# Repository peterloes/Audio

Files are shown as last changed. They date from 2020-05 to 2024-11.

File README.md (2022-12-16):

# Audio
 designed with MOMO 
 
Authors: Loës P., Kempenaers B.(2020) 

Firmware not reviewed. 

Platform for animal observation and manipulation.

Supported:
- FN-RM01 MP3/WAV Audio Recorder and Player Module (Website: www.flyrontech.com)

The Project is used to playback and record sounds, target manipulated via pit-tag numbers.
Uses the Audio Module FN-RM01 which handles automatic playback and record files.

An efficient application to monitor and control animal behaviour in wildlife
as well as in laboratory settings

-	Targeted manipulation of 1000 and more individuals
- Pit-tag numbers targeting Playback-Soundfiles or Record-Soundfiles 
- Playback Audio files P001.wav/mp3 up to P005.wav/mp3 over time
- Random Playback Audio files P001.wav/mp3 up to P005.wav/mp3 over time
- Record Audio files R001.wav up to R999.wav over time
- Combined Audio Playback and Record over time
- There are two special IDs:

  "ANY" means there was a transponder detected, but its ID is not listed.

  "UNKNOWN" means that NO transponder could be detected

My image

-	Low power consumption and specific data collection lead to long lasting collection periods
-	Applicable world-wide due to its compatibility with different types of radio clock receivers 
-	Data-transfer to external devices, such as personal computers
- Time Synchronization with atomic clock once a day to ensure optimal data quality
- Application Current Control twice a day
- Forecast for Battery-Change implemented
- Energy Bypass so that Date and Time are maintained even when changing battery
- Hyperterminal Output to get real-time data to the computer/laptop

My image

Prototype: Smart Nest Box with microphone and speaker on top

https://github.com/peterloes/Audio/blob/master/Getting_Started_Tutorial/1_poster_overview.pdf

Raw data on SD Card:

https://github.com/peterloes/Audio/blob/master/Getting_Started_Tutorial/6_raw_data.txt

Configuration data on SD Card:

https://github.com/peterloes/Audio/blob/master/Software/CONFIG.TXT

Mainboard:

https://github.com/peterloes/MOMO

Optional components:

https://github.com/peterloes/Booter_RFID-MS_MOMO_TAMDL

https://github.com/peterloes/Clock_receiver_RFID-MS_MOMO_TAMDL

Manufacture:

https://github.com/peterloes/Audio/blob/master/Getting_Started_Tutorial/5_Supplier.txt

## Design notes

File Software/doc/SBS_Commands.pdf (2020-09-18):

# Projekt U-BMS2-4

# SBS-

# Commands

# SBS Commands

Device Address | | | | | | 0x0A
ManufacturerAccess | | | | | | 0x00

Read word

RemainingCapacityAlarm | 0x01

Read word
Rückgabe des remainingCapacityAlarm-Wertes in [mAh].

Wenn die Restkapazität(remainingCapacity) kleiner als der Wert vom RemainingCapacityAlarm ist, sendet die Batterie eine Alarmwarnung zum Host. Der RemainingCapacityAlarm-Flag im Battery-Status wird gesetzt.

RemainingTimeAlarm | 0x02

Read word
Rückgabe des remainingTimeAlarm -Wertes in [min].

Wenn die durchschnittliche Entladezeit des Akkus(AverageTimeToEmpty) kleiner als der Wert vom
RemainingTimeAlarm | ist, | sendet | die | Batterie | eine | Alarmwarnung | zum | Host. | Der
RemainingTimeAlarm-Flag im Battery-Status wird gesetzt.
Battery Mode | | | | | | 0x03

Read word

Bit | Beschreibung

### 12 BALANCING CELL3

### 11 BALANCING CELL2

### 10 BALANCING CELL1

### 6 BALANCING CELL4

### 5 Deep Under Voltage recovery(DUVRD) Bit vom FET Control and Status-Register

(FCSR)

### 4 Current Protection Status (CPS) Bit vom FET Control and Status-Register (FCSR)

### 3 Discharge FET (DFE) Bit vom FET Control and Status-Register (FCSR)

### 2 Charge FET (CFE) Bit vom FET Control and Status-Register (FCSR)

CoreTemperature | 0x08

Read word
Die aktuelle Chip-Temperatur in [°K]
Voltage | 0x09

Read word
Die gesamte Akkuspannung in [mV]
BatteryCurrent | 0x0A

Read word
Der aktuelle Strom in [mA], der aus bzw. in den Akkupack durchfließt.
BatteryAverageCurrent | 0x0B

Read word
Der durchschnittliche Strom des Akkupacks in [mA]
RelativeStateOfCharge | 0x0D

Read word
Der relative Ladezustand des Akkupacks in [%]
AbsoluteStateOfCharge | 0x0E

Read word
Der absolute Ladezustand des Akkupacks in [%]
RemainingCapacity | 0x0F

Read word
Die Restkapazität des Akkupacks in [mAh]
FullChargeCapacity | 0x10

Read word
Rückgabe der vollen Ladekapazität in [mAh]
RunTimeToEmpty | 0x11

Read word
Die Ladezeit in [min]
AverageTimeToEmpty | 0x12

Read word
Die durchschnittliche Entladezeit [min]
AverageTimeToFull | 0x13

Read word
Die durchschnittliche Ladezeit in [min]

ChargingCurrent | 0x14

Read word
Der Ladestrom in [mA]
ChargingVoltage | 0x15

Read word
Die maximale Ladespannung in [mV]
Battery Status (flags) | 0x16

Read word

Bit | Beschreibung

### 15 Over Charged Alarm

Überprüfung des chargingProhibited-Flags

### 14 Terminate Charge Alarm

Überprüfung des voltageTooHigh-Flags

### 12 Over Temp Alarm

Überprüfung des cellTemperatureTooHigh -Flags

### 11 Terminante Discharge Alarm

Dieses Bit wird gesetzt, wenn die Restkapazität unter dem definierten Wert von SBS_TERMINATE_DISCHARGE_LIMIT (Standard 5mAh) liegt. Wenn ein Ladegerät erkannt wird, wird dieses Bit gelöscht.

### 10 Battery Protection Triggered

Dieses Bit wird gesetzt, wenn die Batterieschutz-Hardware die FETs ausschaltet.

### 9 Remaining Capacity Alarm

Dieses Bit wird gesetzt, wenn die Restkapazität weniger als der definierte Wert des Restkapazität-Alarms(RemainingCapacityAlarm) ist.

### 8 Remaining Time Alarm :

Wenn die durchschnittlische Entladezeit (AverageTimeToEmpty) kleiner als der definierte Wert des Entladezeit-Alarms (RemainingTimeAlarm) ist, wird dieses Bit gesetzt.

### 7 Initialized

Dieses Bit wird gesetzt, wenn die Initialisierung erfolgreich abgeschlossen ist.

### 6 Discharging

Dieses Bit wird gesetzt, wenn ein Entladestrom fließt.

### 5 Fully Charged

Dieses Bit wird gesetzt, wenn die Batterie vollständig geladen ist. Wenn ein Entladestrom aus der Batterie fließt, der höher als der Standby-Stromwert ist, wird dieses Bit gelöscht.

### 4 Fully Discharged

Dieses Bit wird gesetzt, wenn die Restkapazität der Batterie bzw. die Zellenspannung sehr niedrig ist. Wenn der relative Ladezustand über 20% steigt, wird dieses Bit gelöscht.

ChargerCycleCount | 0x17

Read word
Die Anzahl der Ladezyklen
DesignCapacity | 0x18

Read word
Die Nennkapazität in [mAh]
DesignVoltage | 0x19

Read word
Die Nennspannung in [mV]
SpecificationInfo | 0x1A

Read word
Die Spezifikation-Info (Version und Revision-Nummer)
ManufactureDate | 0x1B

Read word
Das Herstellungsdatum
SerialNumber | 0x1C

Read word
Die Seriennummer
ManufacturerName | 0x20

Read Block
Der Name des Herstellers
DeviceName | 0x21

Read Block
Der Name des Gerätes
DeviceChemistry | 0x22

Read Block
Die chemische Bezeichnung des Gerätes
ManufacturerData | 0x23

Read Block
Die Herstellerdaten
ShuntResistance | 0x2A

Read word
Der Wert des Shunt-Widerstands in [µOhm]

CellsInSeries | 0x3C

Read word
Anzahl der verwendeten Zellen in Serie
OverCurrentReactionTime | 0x3D

Read word
Überstrom Reaktionszeit Stufe 1
OverCurrentCharge | 0x3E

Read word
Überladestrom Stufe 1
OverCurrentDischarge | 0x3F

Read word
Überentladestrom Stufe 1
HighCurrentReactionTime | 0x40

Read word
Überstrom Reaktionszeit Stufe 2
HighCurrentCharge | 0x41

Read word
Überladestrom Reaktionszeit Stufe 2
HighCurrentDischarge | 0x42

Read word
Überentladestrom Stufe 2
VoltageCell4 | 0x44

Read word
Rückgabe der Spannung der Zelle 4 in [mV]
VoltageCell3 | 0x45

Read word
Rückgabe der Spannung der Zelle 3 in [mV]
VoltageCell2 | 0x46

Read word
Rückgabe der Spannung der Zelle 3 in [mV]

VoltageCell1 | 0x47

Read word
Rückgabe der Spannung der Zelle 1 in [mV]
CellMinVoltage | 0x54

Read word
Die minimale Zellenspannung in [mV]
CellMaxVoltage | 0x55

Read word
Der Wert der maximalen Zellenspannung in [mV]
CellPowerOffVoltage | 0x55

Read word
Der Wert der Zellenspannung in [mV], bei der das BMS in den PowerOffModus geht

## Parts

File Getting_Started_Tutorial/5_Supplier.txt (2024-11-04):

Active antennas
DCF77 Empfänger AASV DCFn PON/Ri/1m Aktivantenne SV DCFn 

HKW-Elektronik GmbH
Jörg Schneider

Eisenacher Str. 42 b
99848 Wutha-Farnroda / Thür.
Germany
Phone:  +49 (0)36921 3080 130
mailto:    schneider@hkw-elektronik.de
www.hkw-elektronik.de

Lightbarriers for front plate nestbox 
Doppel - Lichtschranke Art.Nr. P00700 (Lichtschranken in Frontplatten):

SWISSSENSOR AG
Geschäftsleitung Hermann Beer

Steinacherstrasse 4
CH-9327 Tübach
Germany
Tel. +41(0)71 845 24 24
mailto:beer@swisssensor.ch
www.swisssensor.ch

Lithium Ionen rechargeable battery pack Art.Nr. 60.16294 Panasonic NCR 18650GA 4S2P
14,4Volt 6900mAh inklusive SMBus Kabel je. 150mm 

DYNAMIS Batterien GmbH
Josef Pfeil

Brühlstraße 15  D- 78465 Dettingen / Konstanz
Tel. +49 (0) 75 33/93 669-15
mailto:josef.pfeil@dynamis-batterien.de
www.dynamis-batterien.de

FN-RM01 MP3/WAV Audio Recorder and Player Module
Flyron Technology Co., Ltd.
Kevin Xu

Skype ID: kevinxu8410
Phone: +86-186 6501 8673
E-mail: kevin.xu@flyrontech.com
Website: www.flyrontech.com

Supplier of all Electronic Boards

Top-Print Electronic GmbH
Oskar Schmid

Rosenheimer Landstr. 129a
85521 Ottobrunn
Germany
Tel.: +49-89-60668047
Fax: +49-89-60668049
mailto: info@top-print.eu
https://www.leiterplatten-muenchen.de/

RFID reader
Nanomodule Multi 125LV A/1.11 (T3NM-LV) 125kHz +/-0,5% Art.Nr. ART10413
ANT002 Rundspule 47mm, 490µH Art.Nr. ART 10668

Elatec GmbH
Felix Ellspermann

Zeppelinstr. 1
82178 Puchheim 
Germany
Tel: +49 89 552 9961 120
mailto: f.ellspermann@elatec.com
www.elatec-rfid.com

Small sized transponder, not uniqued.
GlassTag 1,41x8,3mm EM4305 134kHz

Rasmus Forntheil
Product Manager Animal ID
RBIS Europe, Smartrac Specialty GmbH

e: rasmus.forntheil@eu.averydennison.com
t: +49 (0) 2265 9919-14  |  m: +49 (0) 173 5688184
Gewerbeparkstr. 10, 51580 Reichshof-Wehnrath, Germany

Internet: https://www.averydennison.com/en/home.html

Protective coating with Schmelzharz Bectron MR3404

KC – Kunststoff- Chemische Produkte GmbH
Holger Sarau-Burghardt

Leonberger Straße 86 
DE 71292 Friolzheim
phone: +49 (0)7044 9425 13
e-mail: h.sarau-burghardt@kc-produkte.com
http: www.conformalcoating.de

Industrial SD Cards ATP 2GB
https://www.atpinc.com/products/industrial-sd-cards

FTDI Chip cable (3.5mm Audio Jack to USB)
TTL-232R-3V3-AJ

Housing
https://www.spelsberg.de/industrieleergehaeuse/glatt-mit-befestigungsnocken/20100701/
TG PC 1612-9-to
Artikelnummer: 20100701 | Maße: 162 x 122 x 90 mm
Leergehäuse IP66 / IP67 Polycarbonat

Docklight RS232 Terminal / RS232 Monitor
https://docklight.de/information/

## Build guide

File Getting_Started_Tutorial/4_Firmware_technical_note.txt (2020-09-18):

MOMO (Multifunctional Mainboard to Observe and Manipulate Organisms) 
is an application to automate the recording and manipulation of animal behavior.

Version 1.3
- Added support for battery controller TI bq40z50.
  LogBatteryInfo: Removed SBS_ManufacturerData.
  Display SBS_RunTimeToEmpty in days/hours/min.
  Display SBS_SerialNumber as hex value.
- CheckAlarmTime to call the respective alarm action if the current time match the alarm time.
  There is only one alarm time. ON_TIME_1/ OFF_TIME_1 --> Alarm 1 (08:30 - 16:00) is ON. 
  Reading the configuration file CONFIG.TXT from the SD-Card and set-up alarm action.
- Corrected decoding of Short-Range(SR) RFID Reader transponder ID.
- Implemented new feature "Absence Detection" which reports when a transponder is no more detected.
- When the "Absence Detection" is configured, disabling the RFID reader is deferred as long as a transponder is still present.

This application consists of the following modules:
 - main.c - Initialization code and main execution loop.
 - DMA_ControlBlock.c - Control structures for the DMA channels.
 - Control.c - Sequence Control module.
 - CfgData.c - Handling of configuration data.
 - ExtInt.c - External interrupt handler.
 - AlarmClock.c - Alarm clock and timers facility.
 - DCF77.c - DCF77 Atomic Clock Decoder
 - clock.c - An implementation of the POSIX time() function.
 - LightBarrier.c - Interrupt logic for the two light barriers,
   enables the RFID reader.
 - RFID.c - RFID reader to receive transponder IDs.
 - BatteryMon.c - Battery monitor, periodically reads the state of the
   battery via the SMBus.
 - LEUART.c - The Low-Energy UART can be used as monitoring and debugging
   connection to a host computer.
 - microsd.c - Together with the files "diskio.c" and "ff.c", this module
   provides an implementation of a FAT file system on the @ref ss8.
 - Logging.c - Logging facility to send messages to the LEUART and store
   them into a file on the SD-Card.
 - PowerFail.c - Handler to switch off all loads in case of Power Fail.

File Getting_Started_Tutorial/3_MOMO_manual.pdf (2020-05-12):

## Max Planck Institute for Ornithology

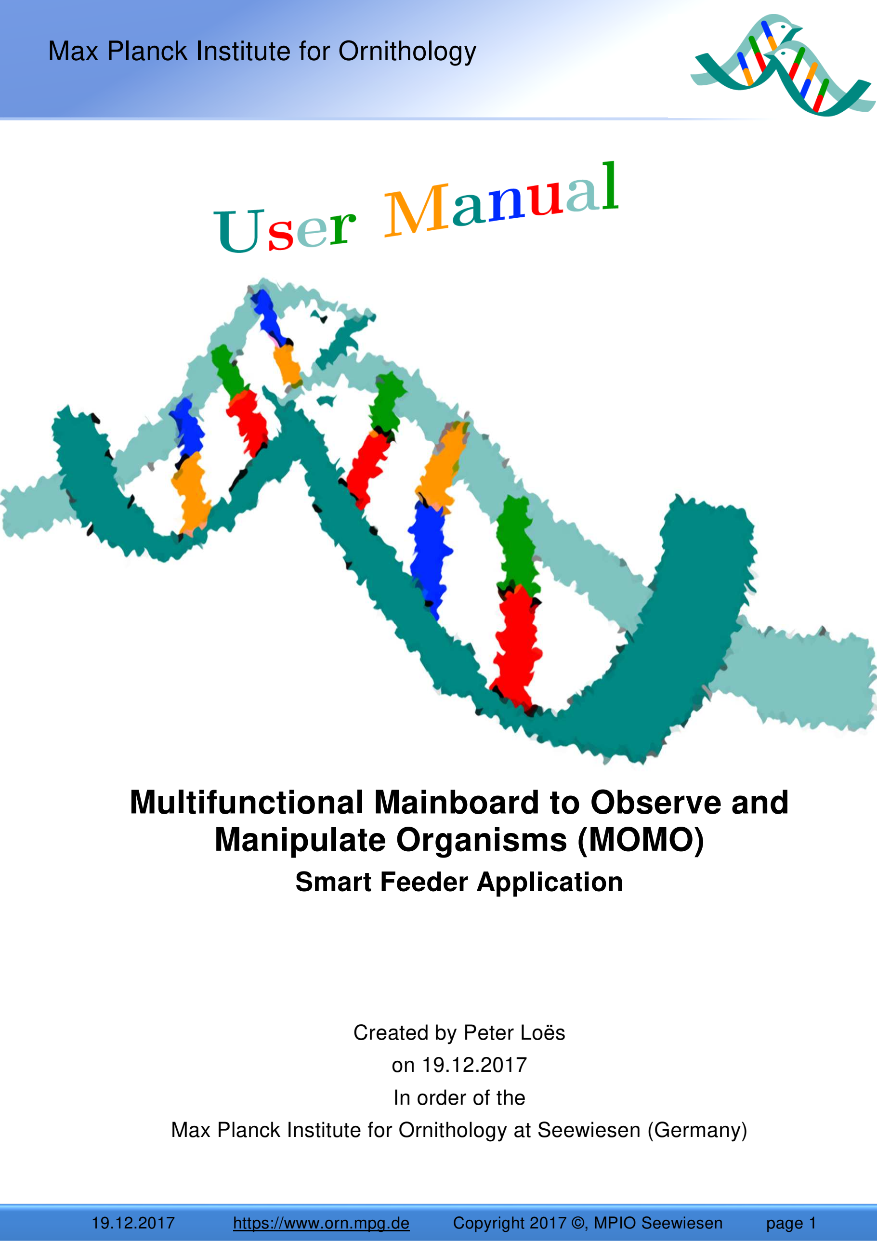
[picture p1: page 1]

19.12.2017 | https://www.orn.mpg.de | Copyright 2017 ©, MPIO Seewiesen | page 1

# Multifunctional Mainboard to Observe and Manipulate Organisms (MOMO)

## Smart Feeder Application

Created by Peter Loës
on 19.12.2017
In order of the
Max Planck Institute for Ornithology at Seewiesen (Germany)

Disclaimer and Copyright

19.12.2017 | https://www.orn.mpg.de | Copyright 2017 ©, MPIO Seewiesen | page 2

## Disclaimer

The Multifunctional Mainboard to Observe and Manipulate Organisms is to be used only as that described in this document. Any other method of usage is not permitted. If damage occurs due to incorrect usage, the manufacturer of the Multifunctional Mainboard to Observe and Manipulate Organisms is not liable.

## Copyright ©

The Copyright for this user manual remains with the manufacturer. Text and figures meet the latest technical status at the time of publication. Subject to change. The content of the user manual shall not affect any claims of the purchaser. The editor also welcomes suggestions of any possible improvements you may have or whether any errors are encountered.

List of abbrevations

19.12.2017 | https://www.orn.mpg.de | Copyright 2017 ©, MPIO Seewiesen | page 3

## List of abbreviations

SF | Smart Feeder
LB | Light Barrier
RFID | radio-frequency identification
EFM | Energy Friendly Microcontroller
PCB | printed circuit board
DCF | D for Deutschland (Germany), C for long-wave transmitter, F due to the vicinity to the Town Frankfurt
ARM | Advanced RISC Machines
SD-CARD | Secure Digital Memory Card
PIT | Passive Integrated Transponder
LEUART | Low Energy Universal Asynchronous Receiver/Transmitter
USB | Universal Serial Bus
MOMO | Multifunctional Mainboard to Observe and Manipulate Organisms

System Overview

19.12.2017 | https://www.orn.mpg.de | Copyright 2017 ©, MPIO Seewiesen | page 4

## System Overview

## General Description of Functions

The Multifunctional Mainboard to Observe and Manipulate Organisms has been developed to record and manipulate animal behaviour. For this purpose, animals got equipped with transponders that can be activated and identified via reading devices. Every animal equipped with a transponder can thereby be identified individually. This technology can be used for every animal species on or in which it is possible to attach a RFID transponder of the size of a rice grain.

Within a population of several individuals carrying a RFID transponder, the Multifunctional Mainboard to Observe and Manipulate Organisms can save the presence and identity of the animals. Whenever an individual with transponder visits a feeder equipped with sensors, the sensor data, transponder code and the timestamp are saved on a SD-card.

Video recordings and visual observations have long been used by biologists to document behaviour of animals and to answer questions about territory, distribution and reproductive behaviour. However, these methods are time consuming, often inexact, and cannot be used when visibility is low (e.g. at night).

To achieve a flexible operation in the field, the Multifunctional Mainboard to Observe and Manipulate Organisms is supplied with electrical energy by a rechargeable accumulator.

The use of electronic devices in the field and nature requires special features in order to operate correctly. Special developments are needed in order to cope with changes in ambient temperature, humidity, pressure and when the electrical power grid is unavailable. However, such developments can be time-consuming and cost-intensive.

Many iterations in the development are needed in order to ensure a stable functioning of electronic products in the wild.

System Overview

19.12.2017 | https://www.orn.mpg.de | Copyright 2017 ©, MPIO Seewiesen | page 5

The Multifunctional Mainboard to Observe and Manipulate Organisms should be placed where the animals of interest often visit, such as feeders, nests, roosts, enclosures or bottlenecks.

One main usage for which the Multifunctional Mainboard to Observe and Manipulate Organisms was developed, is the feeder. Bird behaviour can be manipulated by rationing or even blocking their access to food. The so called ‘Smart Feeder’ records the bird’s presence and therefore provides information about their distribution and foraging behaviour.

A key strength of the Multifunctional Mainboard to Observe and Manipulate Organisms is that it runs autonomously. During the development, special attention was paid developing an energy saving operation, so that a battery pack would only have to be changed every two weeks up to several months, depending on the activity of the smart feeder. The SD cards used have enough memory space to save data for several months of data collection. These low operating expenses make the Multifunctional Mainboard to Observe and Manipulate Organisms (MOMO) ideal for a use in isolated locations without grid connection. Furthermore, biological data is optimally collected when disturbance to the animal’s behaviour due to human presence is minimised. Compared with video recordings and observations, data generation is less error-prone and an increase of data volume is easily realizable. Nevertheless, MOMO also supports an activation and deactivation of video devices or cameras.

MOMO regularly surveys and documents the state of the smart feeder electronic system. A regular evaluation of these data can detect faulty systems and a necessary maintenance can be performed.

The Multifunctional Mainboard to Observe and Manipulate Organisms is currently used for animals with a diameter of less than 70mm, which is contingent upon the antenna of an animal transponder reader. Larger antennas with only marginal overhead are imaginable though, enabling a detection of larger animals as well.

System Overview

19.12.2017 | https://www.orn.mpg.de | Copyright 2017 ©, MPIO Seewiesen | page 6

Some examples of potential uses are:

- nest boxes of birds
- roosting boxes of bats
- studying and monitoring mammals like rats, mice, hamsters, badgers,

squirrels
- reptile research
- studying and monitoring fish
- studying breeding behaviour
- studying movement and dispersal of animals
- choice of nest boxes or roosts

System Overview

19.12.2017 | https://www.orn.mpg.de | Copyright 2017 ©, MPIO Seewiesen | page 7

## System configuration main circuit board

The smart feeder was developed over several years. After five years of development a reliable and efficient version was completed, which is described comprehensively in this manual. Additional detailed information, particularly concerning the electronic configuration, can be found in the datasheet.

Hardware Illustration (MOMO)

System Overview

19.12.2017 | https://www.orn.mpg.de | Copyright 2017 ©, MPIO Seewiesen | page 8
1 | Reset push button | 14 | Gold Cap Capacitor
2 Connections for linear actuator | control | 15 Connecting terminal for the radio clock
3 Connections for two passive | infrared detectors [3.5V@200mA] | 16 Output voltage | 3.5V-11V@ 2.5A for e.g. cameras
4 | Connections for limit switch | 17 | Output voltage 3.5V-11V@ 2.5A for e.g. cameras
5 Power supply for servomotor | [12V@1.5A] | 18 Power supply light barrier
6 Power supply for linear actuator | [12V@1.5A] | 19 Connecting terminal for switchable | RFID readers[12V@0.22A]
7 Connections for switchable power | supplies for three RFID readers | 20 | Connections for the SMBus „System Management Bus“ of the battery pack
8 | Power supply for MOMO | 21 | LEUART connector
9 | Down converter | 22 | LED display devices
10 Switchable power supply for three | RFID readers [3.5V@200mA] | 23 Connections for RFID reader serial bus
11 | Debug Interface | 24 | Connections for buses of the three RFID readers
12 Connections for buses of | servomotor | 25 Two connecting terminals for output of | 3.5V-11V@ 2.5A for e.g. cameras

13 Microcontroller EFM32G230

System Overview

19.12.2017 | https://www.orn.mpg.de | Copyright 2017 ©, MPIO Seewiesen | page 9

Buttons

A ‘reset’ pushbutton is installed on the mainboard of the Multifunctional Mainboard to Observe and Manipulate Organisms, which restarts MOMO.

Connections for linear actuator control

A linear drive or linear drive system refers to all drive systems that lead to a translational movement. Linear drives enable the movement of machines (or elements of them) and facilities (or parts of them) on a straight line or on other default routes.

System Overview

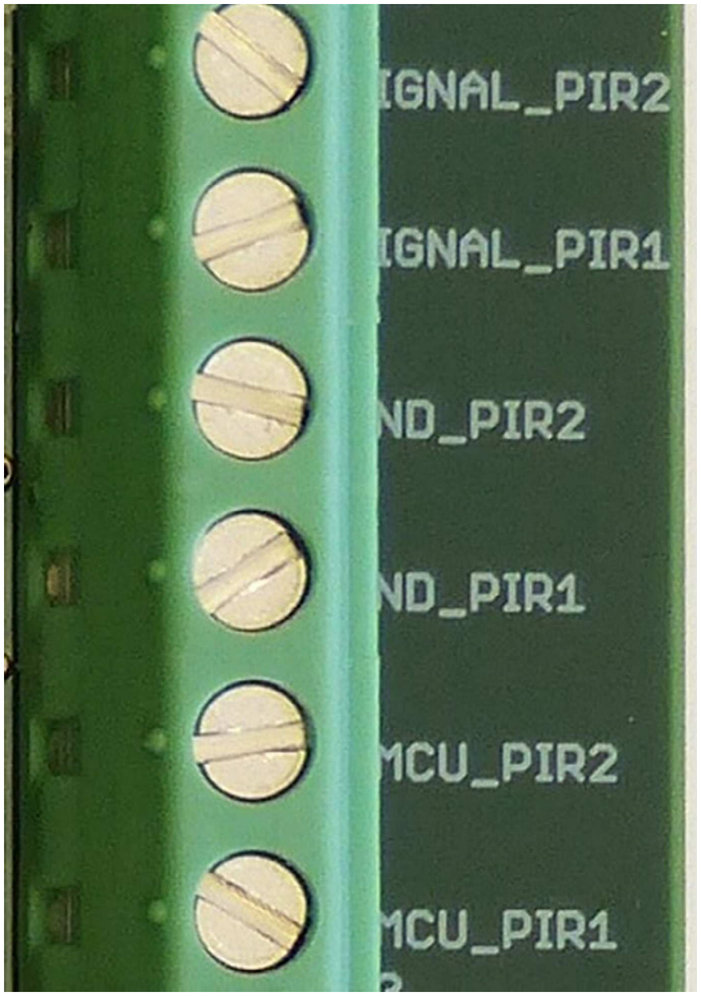
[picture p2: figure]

19.12.2017 | https://www.orn.mpg.de | Copyright 2017 ©, MPIO Seewiesen | page 10

Connections for two passive infrared detectors

A motion sensor is an electronic sensor, which detects movements within its proximity, enabling it to function as an electrical switch. Its main usages are the activation of lighting or alarms.

A motion sensor can work actively using electromagnetic waves (HF or Doppler radar) and ultrasonic (ultrasonic motion sensor) or passively using the infrared radiation of the surroundings – combinations are possible.

The most commonly used type of motion sensors is the PIR-Sensor (passive infrared) is. It reacts ideally towards angular changes, e.g. when someone passes the sensor.

Connections for limit switch

Limit switches (also called end switches or boundary sensors) are sensors that detect when a moved item (e.g. a work piece or a machine component) reached a certain position. The produced signal can be transmitted electrically, pneumatically or mechanically. Within sequence control systems in engineering that consist of several working steps, limit switches detect the end of a movement and thereby induce the next step of the process. They are also used as safety switches (e.g. door closed) to prevent human and mechanical damages.

System Overview

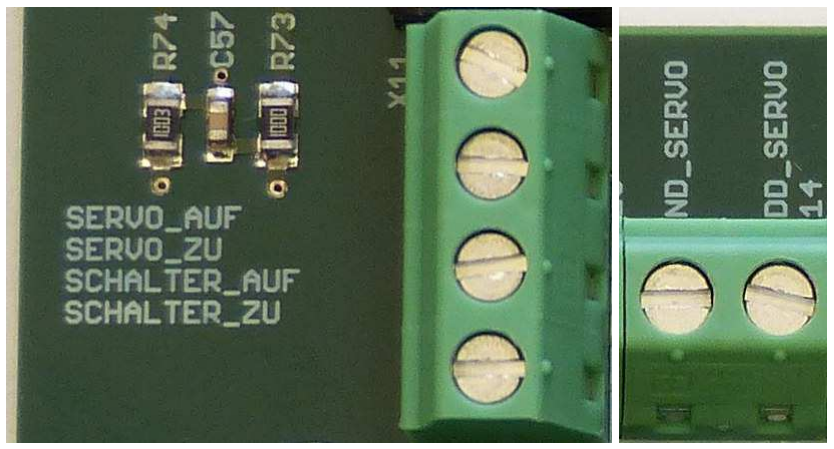
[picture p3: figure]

19.12.2017 | https://www.orn.mpg.de | Copyright 2017 ©, MPIO Seewiesen | page 11

Power supply for servomotor

Special electro motors enabling a control of their angular position as well as of their motor shaft and their speed of rotation are termed servomotors. They consist of an electromotor that is additionally equipped with a location determination sensor. The angular position of the motor shaft, detected by the sensor, gets continuously forwarded to an electronic control system - the so called servo controller, which is usually fixed outside of the actual motor. The servo controller then regulates the movement of the motor via a control circuit, corresponding to one or more adjustable set values like a set angular position, the shaft or the set rotation speed.

Connections for three RFID reading devices

RFID (radio-frequency identification) describes a technology for transceiver systems that uses automatic and non-contact identification and localisation of objects and living organisms with radio waves.

A RFID system consists of i) a transponder (sometimes referred to as radio tag) that is located on or within the object or living organism and contains an individual label and ii) a reading device for the readout of that label.

RFID transponders can be as small as a rice grain and implemented into e.g. pets or humans. Moreover, there is the possibility of producing the RFID transponders via a special printing technique of stable circuits made from polymers. The benefits of this technique emerge from the combination of a small size, an inconspicuous readout possibility (e.g. in the newly introduced ID card in Germany

System Overview

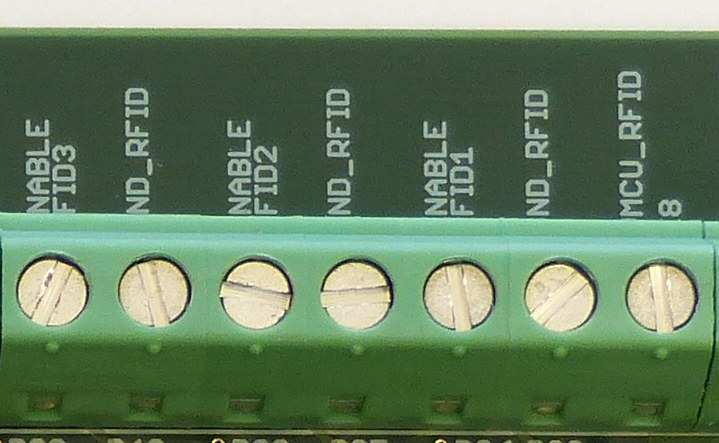
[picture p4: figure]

19.12.2017 | https://www.orn.mpg.de | Copyright 2017 ©, MPIO Seewiesen | page 12

on the 1st of November 2010) and the low price of the transponder (sometimes even cents). This new technique could potentially replace the nowadays commonly used barcode.

The coupling takes place through an – by the reading device created – alternating magnetic field in short range or via high frequency radio waves. Thereby data gets transferred and the transponder is provided with energy. For an attainment of longer ranges, active transponders with an in-built power supply are used, that, on the downside, come along with higher costs.

The reading device contains a software (a microprogram) that controls the actual reading process and a RFID middleware with digital interfaces for further EDV systems and databases, see RFID buses of the MOMO circuit board.

System Overview

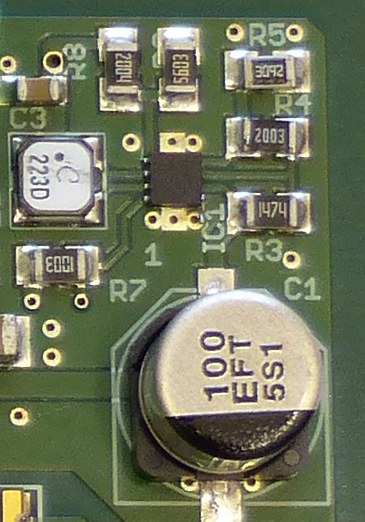
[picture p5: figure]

19.12.2017 | https://www.orn.mpg.de | Copyright 2017 ©, MPIO Seewiesen | page 13

Power supply for MOMO

The Texas Instruments TPS62125 3-17V down converter is a highly efficient device, optimized for applications with low and very low power drain of up to 300mA output current. The large input voltage range of 3V to 17V supports four alkali-cells and one to four LiP battery-cells in serial configuration as well as applications powered with 9V and 15V. The down converter TPS62125 owns a precise low-consumption comparator, which is used for input voltage control to meet system specific requirements during power on and off.

Debug Interface (DBG)

The debug interface software is stored on the microcontroller flash memory. Only after the flash memory contains this information, the hardware can be operated. The connection is either realised directly with a USB cable to the
debug interface or with a debugging probe. If
the connection is realized directly through the
USB cable only HEX files and BIN files can be transferred.

System Overview

19.12.2017 | https://www.orn.mpg.de | Copyright 2017 ©, MPIO Seewiesen | page 14

EFM32 Microcontroller

So called microcontroller (MCU) are flip chips that, at the same time, contain a processor and peripheral functions. In many MCUs, the internal and program memory are located partially or entirely on the same chip.

EFM32 is a family of microcontrollers offered by
Silicon | Laboratories. | The | EFM32 | are | 32-bit
microcontrollers of different sub-families that use ARM cortex-M3 processors. The energy consumption received special focus during the development, which
influenced naming: EFM stands for Energy Friendly
Microcontrollers. The low power demand makes the
EFM32 microcontroller especially suitable for applications with battery supply. EFM32 microcontroller contain several energy-saving modes that can be changed easily. Additionally, many peripheral devices can be plugged.

Within the Animal Presence RFID Data Logger the EFM32G230 microcontroller is used with 128 KB Flash Memory and 16 KB RAM Memory.

The EFM32 series is also known as “Gecko” by the developer, as these animals consume only 10% of the energy used by a mammal of similar size.

Energy Micro states that benchmark measurements with other leading energy saving MCU’s, found that the EFM32-MCU consumes only a quarter of the energy consumed by the other 8-, 16-, or 32-bit-MCU’s.

The EFM32 microcontroller based on the ARM Cortex processor is well suited for energy saving applications such as:

- electricity-, gas- and water-meters
- factory automation and building automation systems
- alarm and security technology as well as portable applications for medical

engineering or within the fitness sector.

The ARM Cortex-M3 processor is developed by Energy Micro and has been bought by Silicon Labs. Since the used processor works with 32 bit, data processing is much faster than 8 and 16 bit CPUs. Therefore, tasks are completed with less clock cycles, which reduces the dwell time in an active mode substantially.

System Overview

19.12.2017 | https://www.orn.mpg.de | Copyright 2017 ©, MPIO Seewiesen | page 15

The EFM32G230 contains an UART-interface for communication with external systems, which is especially designed for energy saving. The interface is referred to as LEUART-interface. LEUART is a serial interface, a kind of bus system. Through the LEUART-interface, a jack connector and a USB cable can be used to establish a connection to a computer.

Capacitor

A capacitor (German “Kondensator”) is a passive electric component with the ability to store electrical charge and electrical energy of a continuous circuit statically in an electrical field.

When the electrical power supply through the battery is
missing, the capacitor ensures an alternate power supply for the Multifunctional Mainboard to Observe and Manipulate Organisms (MOMO). The capacitor is charged when the accumulator supplies energy to the system. This allows energy to be obtained for a certain time from the capacitor if it is required.

Especially the clock of the microcontroller continuous to be powered when there is no external electrical power supply.

Some applications only become possible through double layered capacitors. Despite its large capacity, it is very small in size. The dielectric strength is not exceptionally high however, with only a few volts. Through its large capacity, the Gold Cap is present to maintain the power supply when the main energy source fails. In devices in which data storage should remain in switched off status, the Gold Cap is particularly well suited.

Life expectancy is limited from roughly 8 to 10 years. When the operating temperature is above optimal or the discharge current is high, the life expectancy and the capacity begin to decline over time. The Gold Cap most appropriate when it is rarely discharged and used with low currents.

System Overview

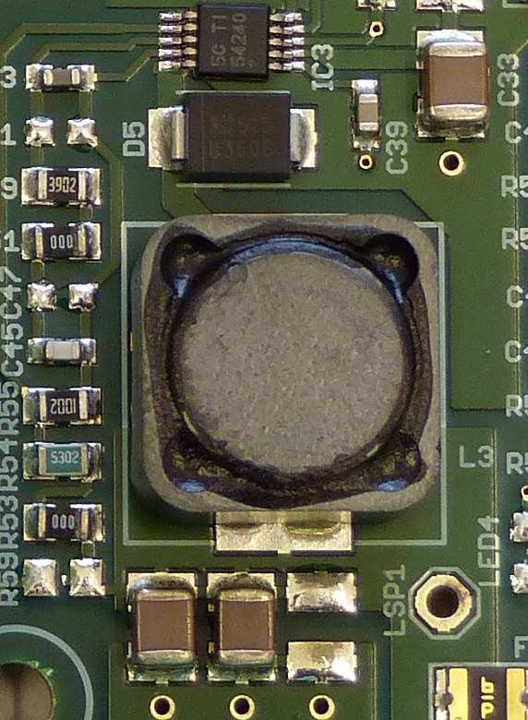
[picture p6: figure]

19.12.2017 | https://www.orn.mpg.de | Copyright 2017 ©, MPIO Seewiesen | page 16

Connecting terminal for the radio clock

See chapter 1.3

Output voltages (down converter)

The TPS62125 3.5V-42V down converter from Texas Instruments is a highly efficient converter, which is optimized for low and ultra-low power applications of up to 2.5 A output current. If no load is recognised by the controller, the standby current is 138 µA. The controller is run by MOMO in the Shutdown Mode. The Shutdown Current is 1.3 µA.

System Overview

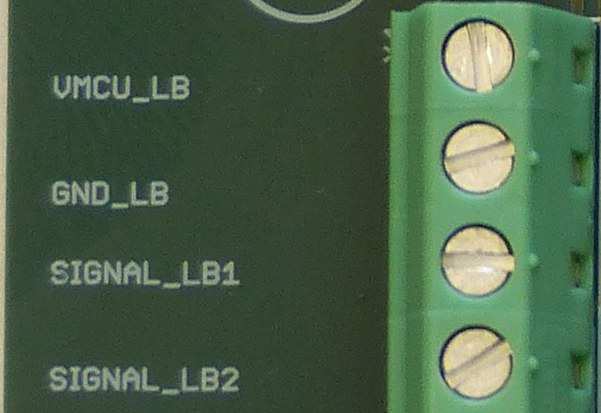
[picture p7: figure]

19.12.2017 | https://www.orn.mpg.de | Copyright 2017 ©, MPIO Seewiesen | page 17

Power supply for light barrier

A light barrier is an optoelectronic system, which indicates an interruption in the beam of light and communicates this event via an
electrical | signal. | This | way, | automatic
devices can detect moving objects without contact. Examples are the detection of obstacles in autonomously closing doors or of invaders via alarm systems.

SMBus „System Management Bus“

MOMO supports following standard communication bus systems:

SMBus „System Management Bus“ (http://www.smbus.org/) as well as the
I²C „Inter-Integrated Circuit Interface“ below a frequency of 100 kHz. https://en.wikipedia.org/wiki/I%C2%B2C

The System Management Bus (SMBus) is
needed for the communication between MOMO and the microcontroller with ‘Battery management system’ (BMS).
For reading the single registers of the microcontroller with BMS via the SMBus, the software commands ‘SBS Commands’ were installed.

System Overview

19.12.2017 | https://www.orn.mpg.de | Copyright 2017 ©, MPIO Seewiesen | page 18

Jack connector as interface to a PC

For the development of the Multifunctional Mainboard to Observe and Manipulate Organisms an Interface for connection to a computer is intended. Through the data communication interface LEUART, which is provided by the microcontroller EFM32G230 out of chapter 1.2.10. The jack
connector is used to connect the signal of the
LEUART interface with a PC. For this, a jack
connector with 3.5 mm, found in many audio applications, is applied. Please regard a power supply of 3.3 V when buying cables.

LEDs

There are two built-in LED’s. The yellow LED (LED 2) indicates, that something is written on the SD card. If the red LED (LED 1) flashes, it indicates that the radio time gets received. If the LED 1 blinks longer than 5 minutes or flashes continuously, this indicates a malfunction.

SD Memory Card Connector

The data from the RAM memory is stored in form of *.txt files on the SD-card, this is located in the SD Memory Card Connector. The size of the memory influences the energy consumption; the smaller the memory size is, the smaller the energy consumption. Therefore, it is recommended for the Multifunctional Mainboard to Observe and Manipulate Organisms
(MOMO) to use a small SD memory size of 2 GB.
Larger memory sizes increase MOMOs Energy
consumption. Memory sizes are supported from 2 GB to 32 GB. Not every event is written onto the SD card immediately. It is first waited for the provided memory to be full. The writing on the SD card consumes quite some energy, which is why the access to the SD card should occur as rare as possible.

System Overview

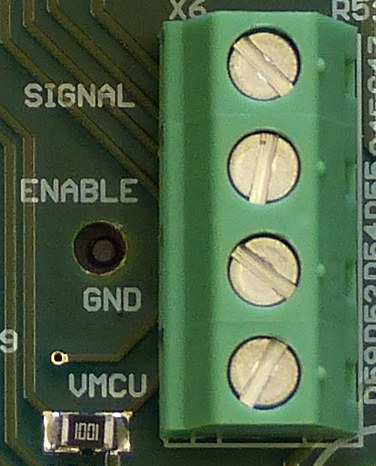
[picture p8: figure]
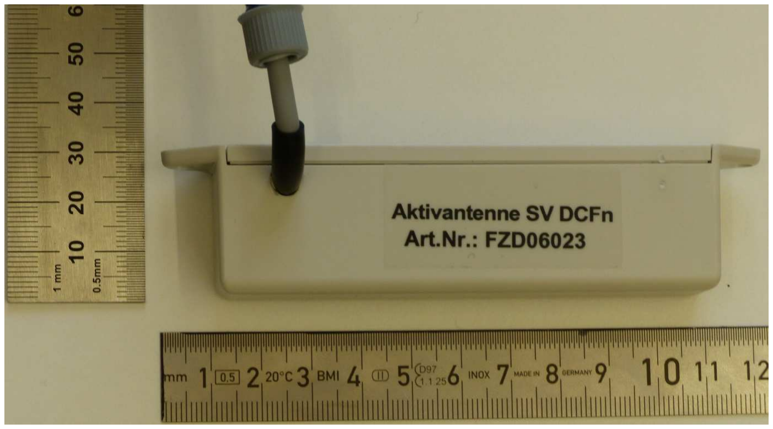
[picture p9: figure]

19.12.2017 | https://www.orn.mpg.de | Copyright 2017 ©, MPIO Seewiesen | page 19

## System configuration radio clock receiver

Connector

Hardware illustration

System Overview

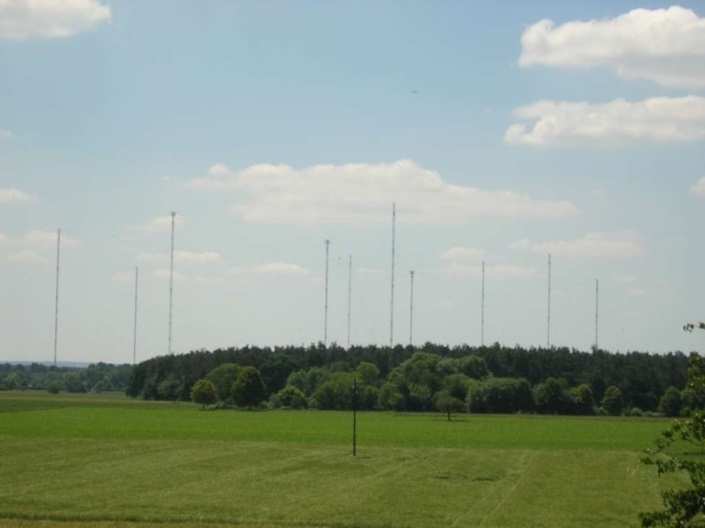
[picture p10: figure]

19.12.2017 | https://www.orn.mpg.de | Copyright 2017 ©, MPIO Seewiesen | page 20

Radio clock

The current version of the Smart Feeder features a radio clock, which works in a similar way as a normal clock. In periodic intervals a signal to Europe from the long wave antenna in Mainflingen with a frequency of 77.5 kHz is received and synchronized. Long wave signals have been compared to short waves and medium waves, and have a relatively high range, making it is possible to receive the signal from Mainflingen with a range of up to 2000 km. On other continents, the time signals can be received as well, though with different frequencies.

The time of the radio clock is prompted every 24 hours by default and gets transferred to the clock of the MCU. A non-standard detection takes place during a reset of the system or after energy supply has been restored, after the capacitor was discharged for too long to bridge power supply and in case of the voltage to come below 1.8 V.

The power supply of the clock is driven
by an accumulator, which is also used for the other electric consumers and is described in chapter 1.7.
countries | designation | frequency
Germany | DCF | 77.5 kHz
France | TDF | 162 kHz
China | BPC | 68.5 kHz
Japan | JJY | 40 and 60 kHz
USA | WWVB | 60 kHz
Russia | Beta | 25 kHz
Great Britain | MSF | 60 kHz

Smart Feeder (Hardware)

19.12.2017 | https://www.orn.mpg.de | Copyright 2017 ©, MPIO Seewiesen | page 21

## Smart Feeder (Hardware)

Peripheral devices are essential for the regular operation of the Multifunctional Mainboard to Observe and Manipulate Organisms. Concerning the Smart Feeder application these include an accumulator, a radio clock receiver, a light barrier board with a light barrier, a RFID reader and a servomotor board with a servomotor.

Hardware illustration Smart Feeder

Smart Feeder (Hardware)

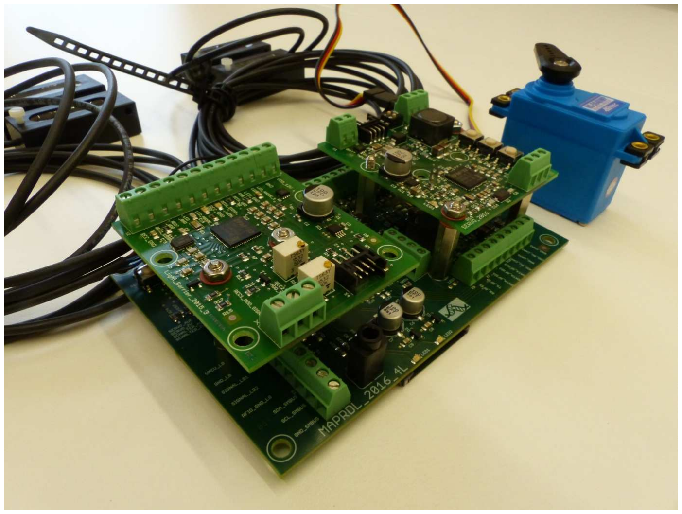
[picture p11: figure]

19.12.2017 | https://www.orn.mpg.de | Copyright 2017 ©, MPIO Seewiesen | page 22

Required boards:

MAPRDL_2016_4L, light barrier actuator, servomotor actuator

Smart Feeder (Hardware)

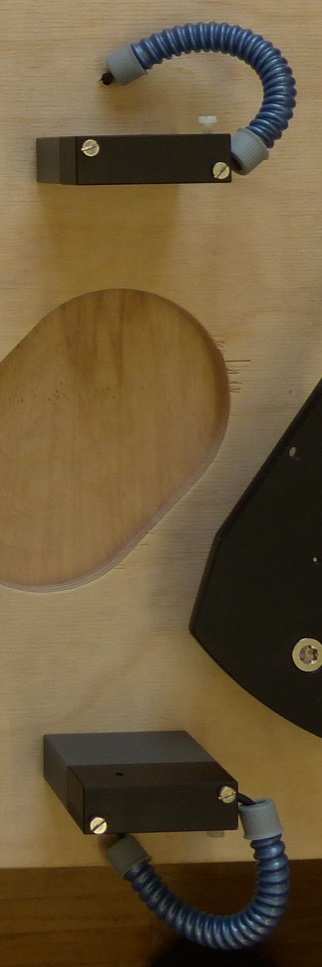
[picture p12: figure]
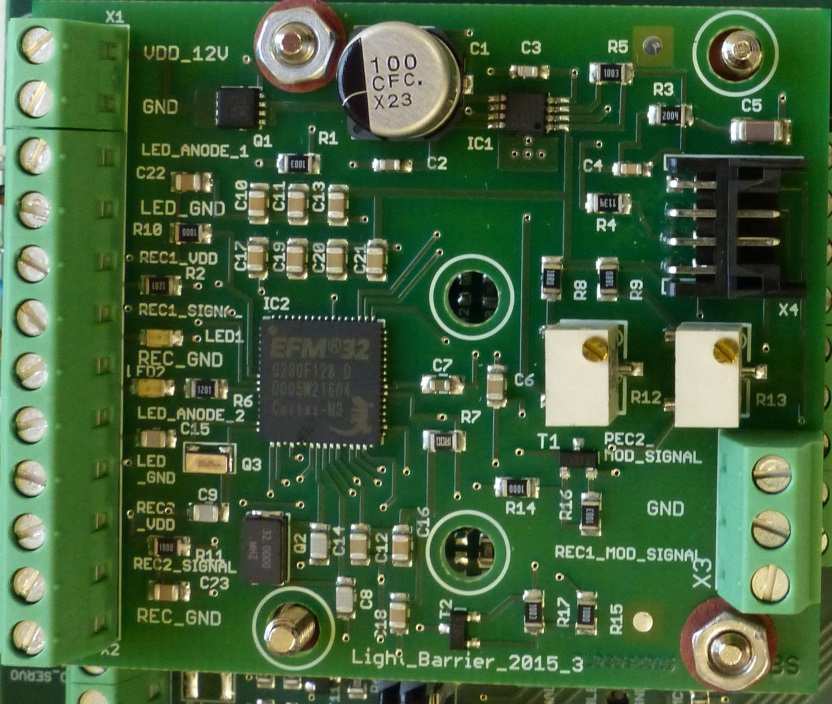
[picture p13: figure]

19.12.2017 | https://www.orn.mpg.de | Copyright 2017 ©, MPIO Seewiesen | page 23

Light barriers

In optoelectronics, a light barrier is system, which indicates an interruption in the beam of light and communicates this event through an electrical signal. Light barriers are composed of a beam source (transmitter) and a photodiode (emitter) to receive the beam.

In the Smart Feeder application, the interruption of an animal is solely detected with light barriers. A maximum of two light barriers can be scanned with up to 100 Hz. The current drain is <120 µA (calculated amount) with a sampling of 10 Hz.

The detection of an object between the light barrier commands an activation of the RFID reader. This needs to occur in a relatively short time, as birds often move quickly. If signal transmission is slower, the RFID reader cannot receive the transponder signal from the bird, because the bird may already be out of range.

The light barriers work with adaptive selectivity, which
means that pollution of the transmitter and emitter, aging or fluctuations due to temperature can be largely compensated for. This reduces the possibility of false detections for example through sunlight.

The required low-power light barrier actuator.

Smart Feeder (Hardware)

19.12.2017 | https://www.orn.mpg.de | Copyright 2017 ©, MPIO Seewiesen | page 24

RFID Reader for transponders

RFID (radio-frequency identification) describes a technology for transceiver systems that uses automatic and non-contact identification and localisation of objects and living organisms with radio waves.

A RFID system consists of a transponder that is located on or within the object or living organism and contains an individual label and a reading device with an antenna for the readout
of that label.

The coupling takes place via alternating magnetic fields produced by the reader within short range or via high frequency radio waves. Thereby, not only data is transmitted, but the transponder is also supplied with energy. Active transponders with a local power source are used to achieve longer ranges, but come along with higher expenses.

RFID’s are also used in other areas such as electronic locks, ski passes, cashless payment transactions, electronic immobilizers and in libraries as theft protection.

The transponder frequency is not exactly the same as the RFID reader frequency. The RFID Reader works with a frequency of 125 kHz and the transponder with 134.2 kHz. However, both systems are compatible and function together.

### 2.1.3.1 RFID receiver module

A RFID receiver module with a frequency of 125 kHz is used in the Smart Feeder application. The used receiver module from Elatec is designed with a small size, small price and versatile applications.

Smart Feeder (Hardware)

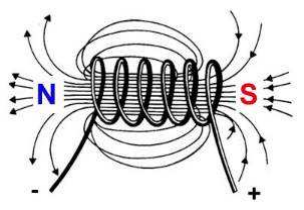
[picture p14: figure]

19.12.2017 | https://www.orn.mpg.de | Copyright 2017 ©, MPIO Seewiesen | page 25

### 2.1.3.2 RFID antenna

The used RFID antenna has a diameter of 50 mm and is directly soldered on the RFID receiver module. If a voltage source is connected to the antenna, which is an air core coil with an inductivity of 490 µH and current begins to flow, an electric field is generated. The electric field is the energy source for the transponder.

If a transponder with its own antenna transmits a signal at a certain frequency, the RFID reader’s antenna collects the signal and transmits it.

### 2.1.3.3 RFID Transponder

The used transponder is the highest performing passive transponder currently available on the market.
These transponders are encapsulated in biocompatible
glass and provide 100% unique identification. Because
of the small size of 8 mm x 1.4 mm and a very low weight of only 30 mg the tagged animals are minimally affected. So it is possible to tag even very small animals such as red ants

The transponder contains a non-volatile flash memory. A combination of letters and numbers is stored on the flash memory during the production of the transponder.

Smart Feeder (Hardware)

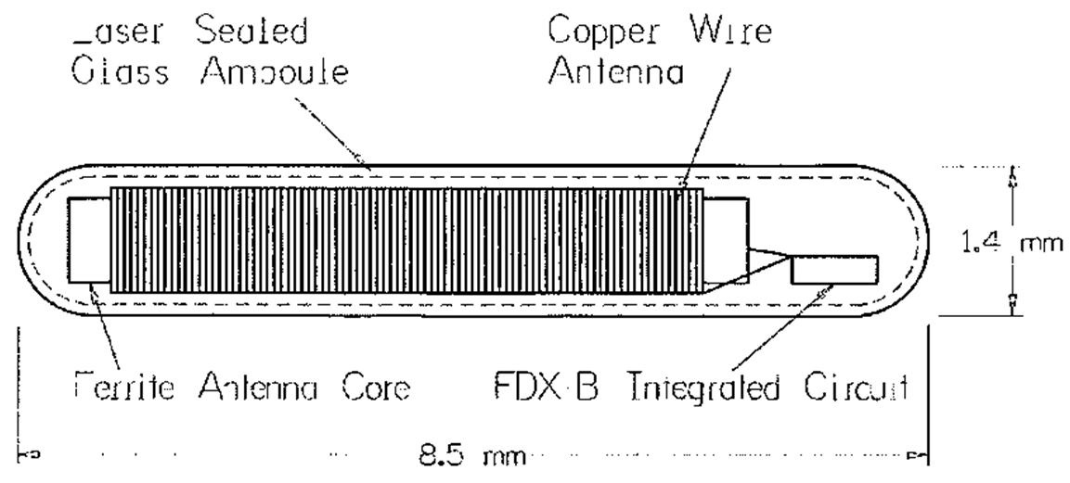
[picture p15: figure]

19.12.2017 | https://www.orn.mpg.de | Copyright 2017 ©, MPIO Seewiesen | page 26
The | transponders | are | known | as | FDX-B
MINIHPT8 and are made by the company Biomark. The FDX-B indicates that the full duplex technique is used.

In duplex mode operating systems the electric
field is always present and the transponder sends its signal as soon as it enters the reception area of the reader. The FDX transponder sends its ID continuously and can therefore be received relatively rapid.

Smart Feeder (Hardware)

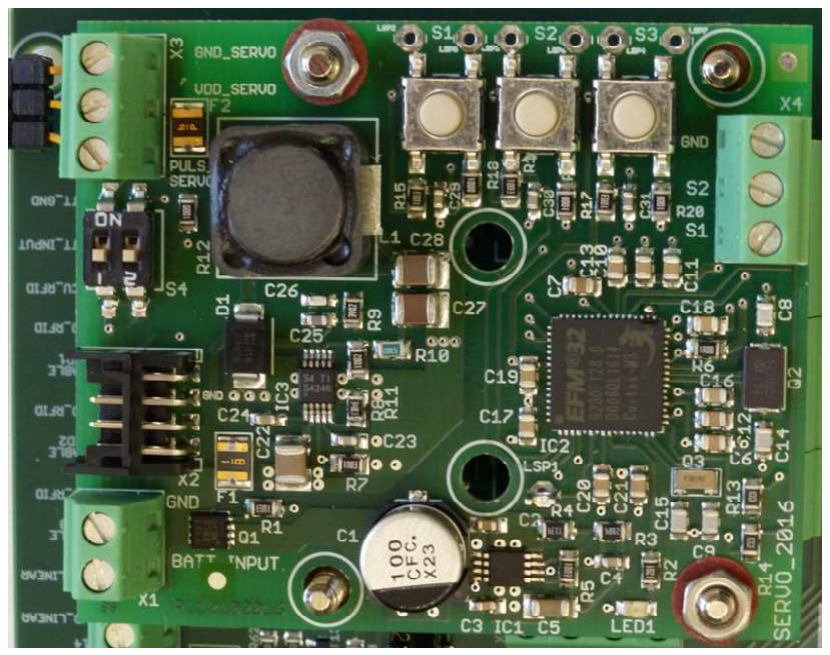
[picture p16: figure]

19.12.2017 | https://www.orn.mpg.de | Copyright 2017 ©, MPIO Seewiesen | page 27

## Servomotor

Food flap | Servomotor HITEC HS-5646WP

The low-power servomotor actuator can be programed manually via the 3 switches. The final positions ‘food flap open’ and ‘food flap closed’ can be set and the processing speed of the flap can be adjusted.

The required low-power servomotor actuator.

Smart Feeder (Hardware)

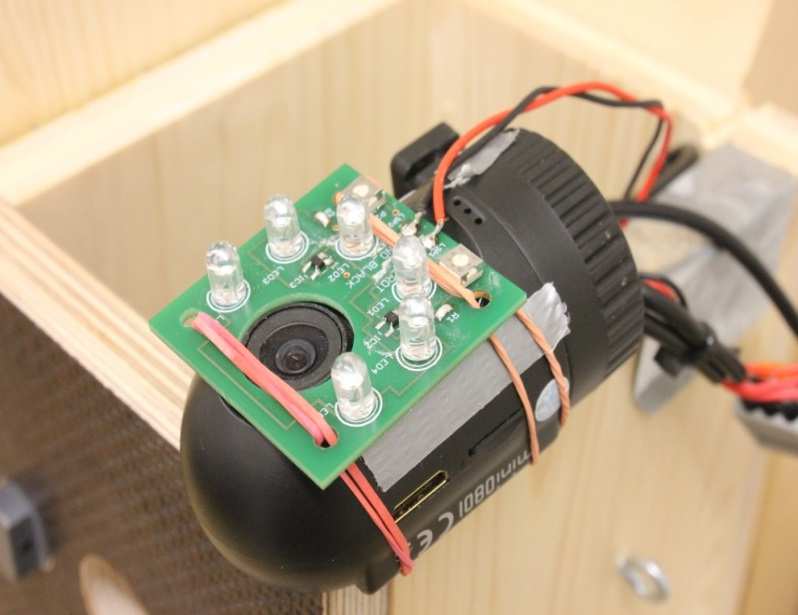
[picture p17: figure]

19.12.2017 | https://www.orn.mpg.de | Copyright 2017 ©, MPIO Seewiesen | page 28

## Dashcam

Video recording device with 12 V battery terminal.

Housing for camera | Full HD Car DVR with GPS

Smart Feeder (Hardware)

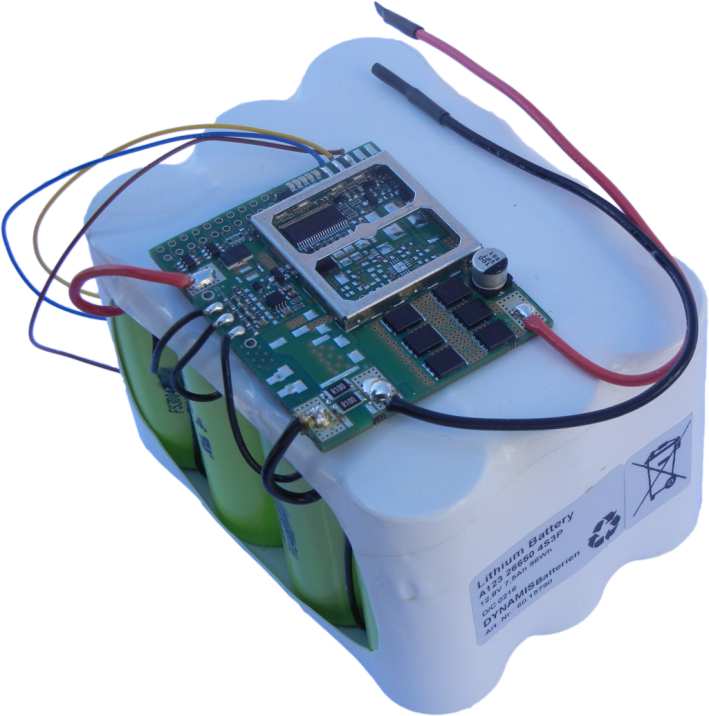
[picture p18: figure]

19.12.2017 | https://www.orn.mpg.de | Copyright 2017 ©, MPIO Seewiesen | page 29

## Accumulator

The lithium-ion battery from the
company | Dynamis | Batterien
supplies Multifunctional Mainboard
to | Observe | and | Manipulate
Organisms (MOMO) with electrical energy. The capacity was chosen to ensure that there is enough energy to supply the Smart Feeder in a very active period for two weeks. Through the little specific energy of the lithium-ion battery of
approximately | 108 Wh/kg, | the
change of the accumulators is much less energy-sapping than with lead-acid batteries with a specific energy of 30 - 60 Wh/kg.

The three LED’s on the accumulator’s board indicates the state of charge. One lit LED indicates that the accumulator is fully charged. Two LED’s indicate the accumulator is halfway charged. Three LED’s indicate an almost empty state of charge

The lithium-ion battery has its own board, which can communicate with MOMO via a bus system. Currently, the temperature of the accumulator, the capacitance values and the latest current drain of the Smart Feeder are prompted from MOMO.

Smart Feeder (Hardware)

19.12.2017 | https://www.orn.mpg.de | Copyright 2017 ©, MPIO Seewiesen | page 30

## Pin assignment and connectors

Pin allocation

### 2.5.1.1 Peripheral terminal

connection | designation | cable colour
X1-2 | BATT_INPUT | red (battery pack)
X1-1 | BATT_GND | brown (battery pack)
connection | designation
X2-1 | VMCU
X2-2 | SWDIO
X2-3: | GND
X2-4 | SWCLK
X2-5 | GND
X2-6: | SWO
X2-7 | frei
X2-8 | MCU_RESET

Smart Feeder (Hardware)

19.12.2017 | https://www.orn.mpg.de | Copyright 2017 ©, MPIO Seewiesen | page 31
connection | designation | cable colour
X3-6 | SIGNAL_PIR2
X3-5 | SIGNAL_PIR1 | red/white LB
X3-4 | GND_PIR2
X3-3 | GND_PIR1
X3-2 | VMCU_PIR2
X3-1 | VMCU_PIR1
connection | designation | cable colour
X4-1 | VMCU_LB | white (RFID)
X4-2 | GND_LB
X4-3 | SIGNAL_LB1
X4-4 | SIGNAL_LB2
X4-5 | RFID_GND_LB | brown (RFID)
connection | designation | cable colour
X5-1 | SDA_SMBUS | blue
X5-2 | SCL_SMBUS | yellow
X5-3 | GND_SMBUS | grey

Smart Feeder (Hardware)

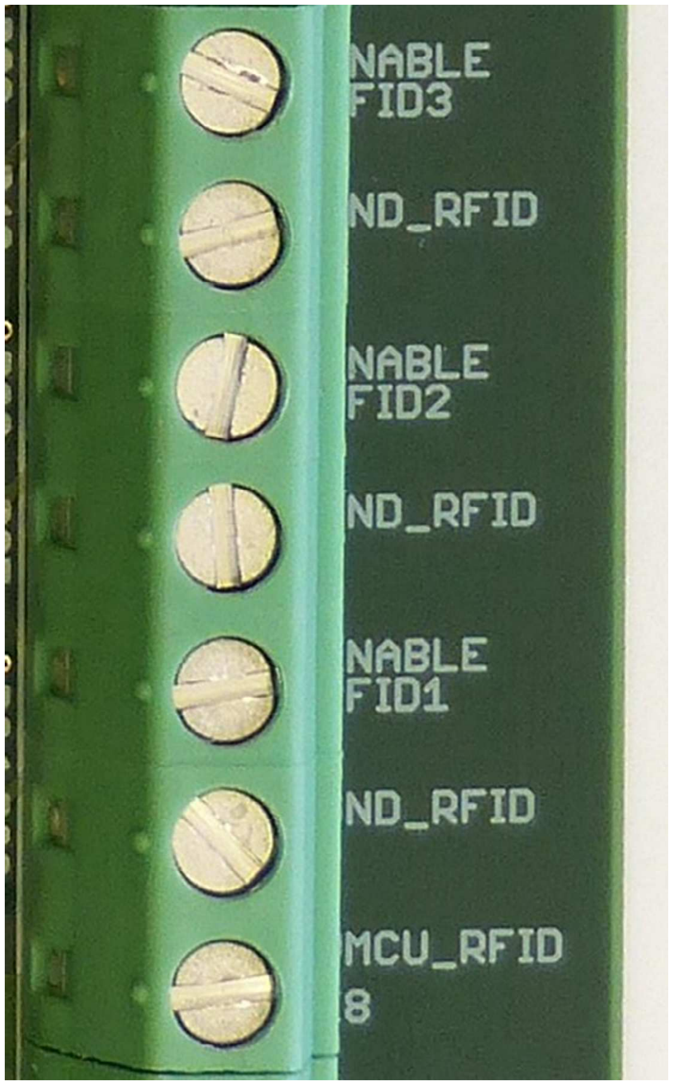
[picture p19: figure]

19.12.2017 | https://www.orn.mpg.de | Copyright 2017 ©, MPIO Seewiesen | page 32
connection | designation | cable colour
X6-1 | DCF_SIGNAL | green
X8-6 | DCF_ENABLE | yellow
X8-5 | DCF_GND | brown
X8-4 | DCF_VMCU | white
connection | designation
X7-1 | DATA_RFID1
X7-2 | DATA_RFID2
X7-3 | DATA_RFID3
connection | designation | cable colour
X8-7 | ENABLE_RFID3
X8-6 | GND_RFID
X8-5 | ENABLE_RFID2
X8-4 | GND_RFID
X8-3 | ENABLE_RFID1
X8-2 | GND_RFID
X8-1 | VMCU_RFID

Smart Feeder (Hardware)

19.12.2017 | https://www.orn.mpg.de | Copyright 2017 ©, MPIO Seewiesen | page 33
connection | designation | cable colour
X9-1 | RX_RFID | grey
X9-2 | TX_RFID | pink
connection | designation | cable colour
X10-1 | VDD_5V_CAM1 | red
X10-2 | GND_CAM1 | black
X10-3 | VDD_5V_CAM2
X10-4 | GND_CAM2
connection | designation | cable colour
X11-1 | SERVO_AUF | red/white
X11-2 | SERVO_ZU | red/white
X11-3 | SCHALTER_AUF
X11-4 | SCHALTER_AUF
connection | designation | cable colour
X12-4 | LINEAR_I_AB
X12-3 | LINEAR_CLK
X12-2 | LINEAR_DIR
X12-1 | LINEAR_ENABLE

Smart Feeder (Hardware)

19.12.2017 | https://www.orn.mpg.de | Copyright 2017 ©, MPIO Seewiesen | page 34

### 2.5.1.2 Jack connectors for LEUART

connection | designation | cable colour
X13-2 | SCHALTER_ZU
X13-1 | SCHALTER_AUF
connection | designation | cable colour
X14-2 | GND_SERVO
X14-1 | VDD_SERVO
connection | designation | cable colour
X15-2 | GND_LINEAR
X15-1 | VDD_LINEAR
connection | designation
J1 | LEUART_RX
J1 | LEUART_TX

Smart Feeder (Hardware)

19.12.2017 | https://www.orn.mpg.de | Copyright 2017 ©, MPIO Seewiesen | page 35

Technical description of additional connectivity options for applications

PA3_CAM1_ENABLE; VDD_5V_CAM1:
Input Voltage Range: 3.5V-11V@2.5A

Applications: recorder, sound player, camera system, animal transponder reader, scale, heater element, cooling element, DC motors, light (infrared, LEDs), temperature sensor, humidity sensor, brightness sensor, motion sensor, light barriers, infrared sensor. Global System for Mobile Communications (GSM), Bluetooth

PA4_CAM2_ENABLE; VDD_5V_CAM2:
Input Voltage Range: 3.5V-11V@2.5A

Applications: recorder, sound player, camera system, animal transponder reader, scale, heater element, cooling element, DC motors, light (infrared, LEDs), temperature sensor, humidity sensor, brightness sensor, motion sensor, light barriers, infrared sensor. Global System for Mobile Communications (GSM), Bluetooth

PA6_RFID_POWER; RFID_GND_LB:
Electrically switchable mass: Input Voltage Range from Circuit: 3.3V@0.22A

Applications: animal transponder reader, heater element, cooling element, motors, light, temperature sensor, humidity sensor, brightness sensor, motion sensor, light barriers, infrared sensor.

PA8_RFID1_DATA:

Device Pinout: TIM2_CC0 #0

The TIMER (Timer/Counter) keeps track of timing and counts events, generates output waveforms and triggers timed actions in other peripherals.

Applications: animal transponder reader, servomotor, counter.

Smart Feeder (Hardware)

19.12.2017 | https://www.orn.mpg.de | Copyright 2017 ©, MPIO Seewiesen | page 36

PA9_RFID2_DATA:

Device Pinout: TIM2_CC1 #0

The TIMER (Timer/Counter) keeps track of timing and counts events, generates output waveforms and triggers timed actions in other peripherals.

Applications: animal transponder reader, servomotor, counter.

PA10_RFID3_DATA:

Device Pinout: TIM2_CC2 #0

The TIMER (Timer/Counter) keeps track of timing and counts events, generates output waveforms and triggers timed actions in other peripherals.

Applications: animal transponder reader, servomotor, counter.

PB12_N_SCHALTER_ZU:
Device Pinout: DAC0_OUT1 #0, LETIM0_OUT1 #1

The DAC is designed for low energy consumption, but can also provide very good performance. It can convert digital values to analog signals at up to 500 kilo samples/second and with 12-bit accuracy.

The LETIMER is a down-counter that can keep track of time and output configurable waveforms. Running on a 32.768 kHz clock the LETIMER is available even in EM2 with sub μA current consumption.

PC0_RFID_RX:
Device Pinout: ACMP0_CH0 #0, PCNT0_S0IN #2, US1_TX #0

The ACMP (Analog Comparator) compares two analog signals and returns a digital value telling which is greater.

The Pulse Counter (PCNT) decodes incoming pulses. The module has a quadrature mode which may be used to decode the speed and direction of a mechanical shaft. PCNT can operate in EM0-EM3.

The USART handles high-speed UART, SPIbus, SmartCards, and IrDA communication.

Smart Feeder (Hardware)

19.12.2017 | https://www.orn.mpg.de | Copyright 2017 ©, MPIO Seewiesen | page 37

PC1_RFID_TX:
Device Pinout: ACMP0_CH1 #0, PCNT0_S1IN #2, US1_RX #0

The ACMP (Analog Comparator) compares two analog signals and returns a digital value telling which is greater.

The Pulse Counter (PCNT) decodes incoming pulses. The module has a quadrature mode which may be used to decode the speed and direction of a mechanical shaft. PCNT can operate in EM0-EM3.

The USART handles high-speed UART, SPIbus, SmartCards, and IrDA communication.

PC8_RFID1_MOSFET, VDD_RFID1:
Input Voltage Range from Circuit: 3.3V@0.2A

Applications: recorder, sound player, camera system, animal transponder reader, scale, heater element, cooling element, DC motors, light (infrared, LEDs), temperature sensor, humidity sensor, brightness sensor, motion sensor, light barriers, infrared sensor. Global System for Mobile Communications (GSM), Bluetooth

PC9_RFID2_MOSFET, VDD_RFID2:
Input Voltage Range from Circuit: 3.3V@0.2A

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

PC10_RFID3_MOSFET, VDD_RFID3:
Input Voltage Range from Circuit: 3.3V@0.2A

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

Smart Feeder (Hardware)

19.12.2017 | https://www.orn.mpg.de | Copyright 2017 ©, MPIO Seewiesen | page 38

PC11_LINEAR_ENABLE:
Device Pinout: ACMP1_CH3 #0, US0_TX #2

The ACMP (Analog Comparator) compares two analog signals and returns a digital value telling which is greater.

The USART handles high-speed UART, SPIbus, SmartCards, and IrDA communication.

PC13_LINEAR_CLK:
Device Pinout: ACMP1_CH5 #0, TIM0_CDTI0 #1/3 TIM1_CC0 #0 PCNT0_S0IN #0

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

The Pulse Counter (PCNT) decodes incoming pulses. The module has a quadrature mode which may be used to decode the speed and direction of a mechanical shaft. PCNT can operate in EM0- EM3.

Smart Feeder (Hardware)

19.12.2017 | https://www.orn.mpg.de | Copyright 2017 ©, MPIO Seewiesen | page 39

## Housing

Housing for the main board

The housing from the main board consists entirely of opaque polycarbonate. The lid is lockable with bayonet locks which are quick and easy to use. The screws are secured from falling out and prevents loss of any screws.

Smart Feeder (Hardware)

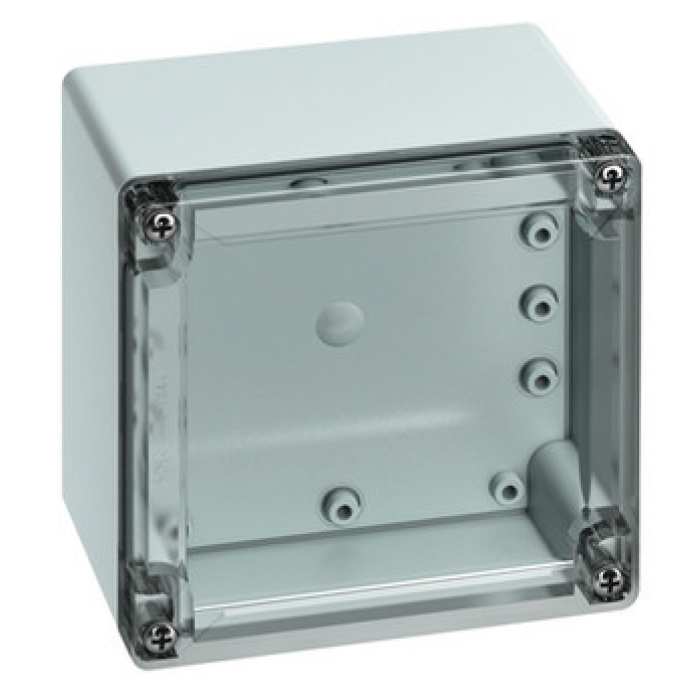
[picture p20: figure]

19.12.2017 | https://www.orn.mpg.de | Copyright 2017 ©, MPIO Seewiesen | page 40

Housing for the accumulator

The housing from the accumulator consists entirely of polycarbonate, with the lid being made from transparent polycarbonate so the LED’s inside may be seen without needing to open the lid. The lid is also lockable with bayonet locks. The same screws are used here and are also secured against falling out.

General working conditions

19.12.2017 | https://www.orn.mpg.de | Copyright 2017 ©, MPIO Seewiesen | page 41

## General working conditions

Component designation | Multifunctional Mainboard to Observe and Manipulate Organisms Smart Feeder Application
Manufacturer | MPIO http://www.orn.mpg.de/
Dimensions main board (L X B x H) | 121 mm x 81 mm x 1,5 mm
Overall temperature range | -10°C to 70°C (DCF77)
Storage temperature range | -20°C to 60°C
Overall moisture | Relative moisture 35% to 85% (at 5 to 35°C)

Detailed information, in particular concerning the electrical properties of the Multifunctional Mainboard to Observe and Manipulate Organisms can be found in the datasheet.

The working conditions from single devices can be found in the datasheets in chapter 8.

Energy supply

19.12.2017 | https://www.orn.mpg.de | Copyright 2017 ©, MPIO Seewiesen | page 42

## Energy supply

The Multifunctional Mainboard to Observe and Manipulate Organisms (MOMO) is especially designed to have low energy requirements. The electrical power requirements are explained more precisely in this chapter.

The EFM32G230 has five different economical energy modes, where only two of which are used for MOMO. These are the Deep Sleep Mode and the Sleep Mode whereby the Sleep Mode is the Active Mode and the Deep Sleep Mode is the Inactive Mode. In these energy modes different consumers are active. The Smart Feeder application of the Multifunctional Mainboard to Observe and Manipulate Organisms switches between the Active Mode and the Inactive Mode through light barrier activity. If the RFID reader and the light barrier detect no activity for 6 minutes, the Smart Feeder switches into the Inactive Mode again to save energy.

The energy-intensive consumers, like the RFID reader, are only supplied with electrical Energy when required. The RFID reader is the largest consumer of electrical energy in the Smart Feeder application, when no camera is connected.

Electrical properties and, to some extent, battery drain, can be drawn from the datasheets of the built-in components. The datasheets are linked in chapter 8.

In the following sections, the current supply and the voltage supply will be exam-ined separately.

Energy supply

19.12.2017 | https://www.orn.mpg.de | Copyright 2017 ©, MPIO Seewiesen | page 43

## Current supply

ARM Cortex Processor

From the five available modes of operation only the Deep Sleep Mode and the Sleep Mode are used.

### 0.9 μA @ 3 V Deep Sleep Mode, including Real Time Clock with 32.768 kHz

Oscillator, Power-on Reset, Brown-out Detector, RAM and CPU retention

### 45 μA/MHz @ 3 V Sleep Mode

RFID

RFID on measured: 35,4mA

RFID off measured: 1,36mA

(from schematics)

Light barriers

The light barriers are always supplied with electricity, independently from the two energy modes. To save energy, the status of the light barrier is not assessed continuously but 100 times per second, thus with a frequency of 100 Hz. Therefore, the light barrier has a very small electrical energy demand of roughly 120 µA.

Radio clock

The clock of the microcontroller is updated at a certain time every night through the time signal from Mainflingen. The radio time will be also updated when the system is reset.

Nominal current 100µA | Quiescent current 5 µA

LED

Each LED has an electric current demand of 2 m. There are two built-in LEDs.

Energy supply

19.12.2017 | https://www.orn.mpg.de | Copyright 2017 ©, MPIO Seewiesen | page 44

Accumulator LED’s and self-discharge

LEDs | electric current demand
Without | 271 µA
Only LED1 | 308 µA
LED1 + LED2 | 343 µA
LED1 + LED2 + LED3 | 384 µA

The self-discharge by lithium-ion-batteries at 20°C is less than 2% per month.

Overview of the nominal currents

This table contains the maximum current demands of the most important devices. If all are active at the same time, the current demand behind the down converter at 3,3 V is 51 mA and with that the maximum power input before the down converter is around 0,1683 W.

devices | currents
RFID | 35.4 mA
2* LED | 2 x 2 mA
ARM Cortex M3 | 45 µA/MHz (1.44 mA)
radio clock | 0.1 mA
light barriers | 2x 120 µA
Total current behind the down converter with 3.3V | 42.2 mA (When all consumers are active at the same time without down converter losses)
Total input in front of the down converter with 12.8 V | 155 mW (When all consumers are active at the same time with down converter losses)

Energy supply

19.12.2017 | https://www.orn.mpg.de | Copyright 2017 ©, MPIO Seewiesen | page 45

Overview of the currents in the different operating modes

| Shutoff Mode | Stop Mode | Deep Sleep Mode | Sleep Mode | Run Mode
RFID | Not used | Not used | Off | Can be on | Not used
ARM Cortex M3 | Not used | Not used | On | On | Not used
Radio clock | Not used | Not used | Can be on | Can be on | Not used
LED’s | Not used | Not used | Can be on | Can be on | Not used
Light barrier | Not used | Not used | On | On | Not used
Down converter | Not used | Not used | On | On | Not used
Accumulator board | Not used | Not used | On | On | Not used

Energy supply

19.12.2017 | https://www.orn.mpg.de | Copyright 2017 ©, MPIO Seewiesen | page 46
| Deep Sleep Mode (inactive mode) | Sleep Mode (active mode)
RFID (with 3.3 V) | 0 | On (35.4mA)
ARM Cortex M3 (with 3.3 V) | 0,9 µA | 45 µA/MHz (1.44 mA)
Radio clock (with 3.3 V) | 0,1 mA (once a day for approx. 5 min; also at reset and start) | 0,1 mA (once a day for approx. 5 min; also at reset and start)
LED (with 3.3 V) | 2 mA (2 units if on) | 2 mA (2 units if on)
Light barrier (with 3.3 V) | 240 µA (2 units) | 30 µA (2 units)
Down converter (3.3 V) | 13 μA | 13 μA
Total current behind the down converter (without down converter losses and 3.3 V) | 0.0609 mA (2 x light barriers and und MCU | 36.88 mA (RFID active, MCU active, light barriers, down converter)
Total input behind of the down converter (without down converter losses and 3.3 V) | 0.0609 mA x 3.3 V = 0.000201 W = 201 x 10^-6 W | 36.88 mA x 3.3 V = 0.122 W
Total input in front of the down con-verter (with down converter losses and 12.8 V) | (with η = 50%) 0.000201W/0.5 = 0.000402 W = 402 x 10^6 W | (with η = 90%) 0.122 /0.9 = 0.136 W
Total current in front of the down converter (with down converter losses 12.8 V) (theoretical) | (with η = 50%) 0.0314 mA | (with η = 90%) 10.6 mA
Measured total current in front of the down converter (with down converter losses 12.8 V) (real) | 0.22 mA = real measured inactive mode (connected radio clock but inactive, controller in Deep Sleep Mode, Gold Cap, connected LED but off, buttons, down converter) | 11 mA = real measured active mode (connected radio clock but inactive, controller, LED connected but off, gold cap, SD card, down converter, light barrier, RFID on)
Accumulator board with LED‘s current demand | (0.271 mA – 0.384 mA) | (0.271 mA – 0.384 mA)
Total current with accumulator board | 0.3024 mA – 0.4154 mA | 10.87 mA – 10.98 mA
Total Input ink. accumulator board with 12.8 V (theoretical) | 0.00387 W – 0.00532 W | 0.139 W – 0.141 W
Total Input with measured value + theoretically accumulator board de-mand with 12.8 V (real) | 0.028 W – 0.0158 W | 0.141 W – 0.142 W

Energy supply

19.12.2017 | https://www.orn.mpg.de | Copyright 2017 ©, MPIO Seewiesen | page 47

## Voltage supply

All consumers are supplied with 3.5 Volts, which are provided by the down converter from the 12.8 Volts from the lithium-ion-accumulator. An input voltage of 5 V for the down converter is sufficient.

## Electrical energy storage

The main power supply is ensured by the lithium-ion-accumulator. If the accumulator is removed, a capacitor ensures the supply.

Accumulator

If the whole capacity of a lithium-ion-accumulator is completely used it can have negative effects on the lifetime of the accumulator. Therefore, a certain percent-age of the total capacity is not used. The accumulator of the Animal Presence RFID Data Logger uses 83% of the total capacity.

Roughly 17 % of the capacity of the accumulator are not used.

voltage | 12.8 V
Nominal capacity | 7.5 Ah
Total capacity | 8.97 Ah
stored energy | 96 Wh

The lithium-ion-accumulator has its own board, which is able to communicate with the Animal Presence RFID Data Reader via a data bus.

Capacitor

If the energy supply from the accumulator is no longer available, a capacitor with

### 0.22 farad ensures the energy supply. The stored energy is enough to supply

MOMO for around 30 seconds. During the discharge, the voltage of the capacitor declines from 3.6 Volts to 1.8 Volts.

Energy supply

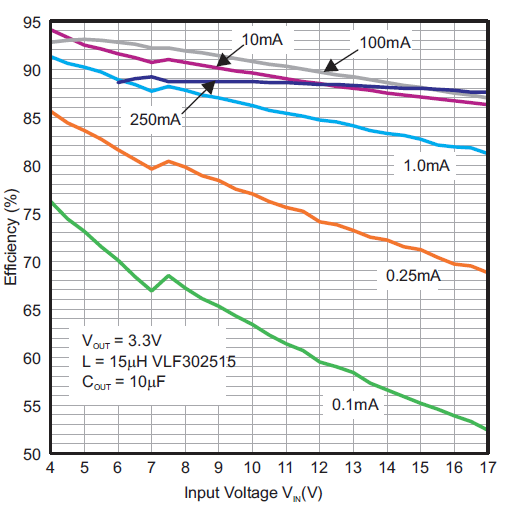
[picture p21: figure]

19.12.2017 | https://www.orn.mpg.de | Copyright 2017 ©, MPIO Seewiesen | page 48

Conversion losses

The accumulator provides electrical energy with a voltage of 12.8 Volts. The EFM32G230 and other consumers require a significantly smaller voltage of around 3.3 Volts. This reduction of voltage is achieved by a down converter which is described in chapter Fehler! Verweisquelle konnte nicht gefunden werden.. The down converter doesn’t work with transformers but with resistors.

Range estimation of the accumulator

Range at maximum power (If the Multifunctional Mainboard to Observe and Manipulate Organisms is always active and there is no maintenance, RFID) | 96 Wh / 0.142 W = 676 hours = 28.16 days
Range at minimum power (The Multifunctional Mainboard to Observe and Manipulate Organisms is in the Deep Sleep Mode and there is no maintenance; radio clock and RFID off, 1x light barrier) | 96 Wh / 0.0058 W = 16552 hours = 690 days = 1.889 years

The value for the range at minimum power can only theoretically be achieved. In reality the self-discharge causes the accumulator to be discharged earlier. Moreover, an inactivity of more than two years is not intended for the application.

Operation of the Smart Feeder

19.12.2017 | https://www.orn.mpg.de | Copyright 2017 ©, MPIO Seewiesen | page 49

## Operation of the Smart Feeder

The operation of the Multifunctional Mainboard to Observe and Manipulate Organisms (MOMO) with the Smart Feeder application will be explained in this chapter. This includes the information detailing accumulator replacement, SD card change, software updates, the loading of the accumulator and troubleshooting.

## Accumulator replacement

The accumulator has to be replaced in periodic intervals. The range of an accumulator depends on several factors, including ambient temperature, activity of the Smart Feeder and therefore energy demand of the Smart Feeder. The activity usually depends on the season of the year. As birds have a higher level of activity near the Smart Feeder (SF) during the winter time, the SF is often in the active mode and needs much more energy than during other seasons.

Reasons for accumulator replacement

The accumulators have boards with three LED’s which indicate the state of charge. If three LED’s are blinking this shows that the accumulator is almost empty and should be exchanged as soon as possible. When two LED’s are blinking the accumulator is half full and one LED blinking indicates an almost full accumulator. If there are no LED’s blinking the accumulator is completely empty and no longer able to supply energy.

When all LED’s are lit permanently this indicates a defect at the accumulator or at the accumulator board. In this case the whole accumulator needs to be changed.

Placement of the accumulator

The wind and therefore also rain, snow and mist in Europe primarily come from the west. This can be seen visibly on trees where the western-facing sides are often moss-covered. Therefore, placement of the accumulator on the eastern side can minimize the possibility of damage due to oxidation.

Moreover, the accumulator can be placed in a way that water can drain away at an edge and does not accumulate at the connector or at the cable input.

Operation of the Smart Feeder

19.12.2017 | https://www.orn.mpg.de | Copyright 2017 ©, MPIO Seewiesen | page 50

If the accumulator becomes warm, it can age more rapidly or be damaged. The operating temperature range of the accumulator is between minus 30°C and 55°C according to manufacturer specifications. When the sun shines directly on the accumulator it is possible to exceed this range. Therefore, the accumulator should be protected against direct sunlight through e.g. placement on the north-facing side of a tree or by shading it in another way.

When placing the accumulator, one should be aware of these external environ-mental influences and place the accumulator appropriately, because of the high costs of the accumulators.

## SD card change

The SD cards have a large memory size so that the memory may be filled only after several months or even years.

As continuous recording of data is desired and as unexpected malfunctions of the Smart Feeders are always a possibility, they should be visited and controlled regularly every couple of weeks. In doing so, SD cards can be exchanged and stored data can be checked. If there is unusual data on the SD cards, it could indicate a malfunction of the Smart Feeder. In this case, a maintenance should be arranged.

## Software update

There are three possible methods to write software code on to the flash memory. The debug probe method from IAR systems and the debug interface method without debug probe are always possible. If software has already been written on the flash memory by either of these methods, an additional method using SD cards is also available.

The microcontroller EFM32G230 contains a flash memory with a memory size of 128 KB. This memory contains the software by which the microprocessor works. 128 KB of memory is a sufficient size for operation, even with very complicated applications of the Multifunctional Mainboard to Observe and Manipulate Organisms. Update possibilities are described in more detail in chapter 7.1.

Operation of the Smart Feeder

19.12.2017 | https://www.orn.mpg.de | Copyright 2017 ©, MPIO Seewiesen | page 51

## Loading the accumulator

The accumulators should be changed and charged in regular intervals. The accumulator has to be visually checked for damage when it is changed.

Recharger

Device description | Mascot type 2541 Li, 4 cell, 2A, Lithium Ion Battery Charger, 35W
Manufacturer | Mascot http://www.mascot.no/home/
Nominal power | 35 W
Battery voltage | 12V
Charging current | Up to 2 A
Recommended battery capacity | 1 – 10 Ah
Loadable cells | 4
Charging characteristic | IUoU

The charge process is separated in to three sections.

### 1. Charging current is 2 A until the voltage reaches 14.7 V 2. Voltage will be held at 14.7 V; Current declines slowly 3. A yellow display shows that the charging current is declined under 1 A

4. If the charging current is below 250 mA the recharger switches off.

### 5. In the maintenance charging module the accumulator voltage will be kept at

13.7 V.

Operation of the Smart Feeder

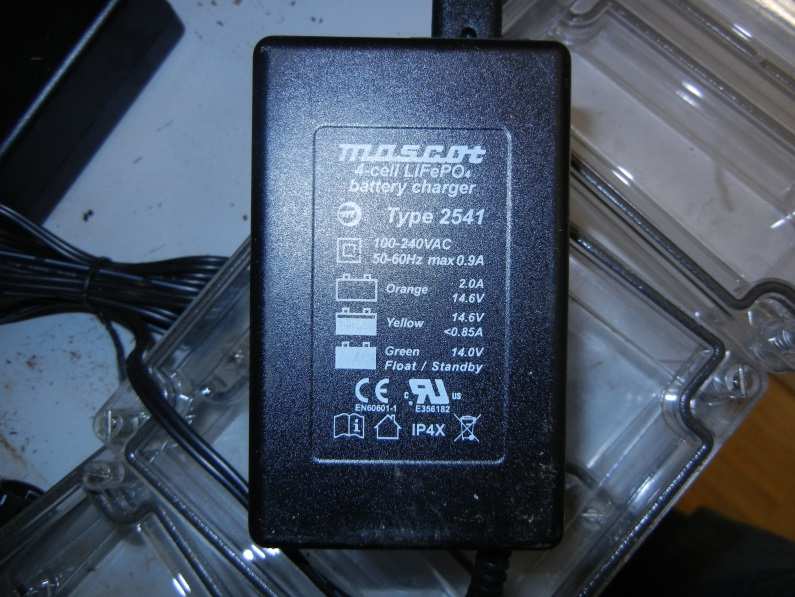
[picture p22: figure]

19.12.2017 | https://www.orn.mpg.de | Copyright 2017 ©, MPIO Seewiesen | page 52

Charging method IUoU

UIoU means that the initial charging current is constant similar to the CCCV charging method until the final charging voltage is reached. Then the voltage is held at the charging end voltage. This constant high voltage can be harmful for the accumulator and reduce the capacity. Therefore, the voltage will be reduced after a certain amount of time; with that the maintenance charging is initiated. With the reduced voltage the accumulator can be charged permanently and the amount of current is roughly like the self-discharge. The “I” in IUoU stands for constant current, “Uo” stands for constant voltage with charging end voltage and “U” for reduced constant Voltage

Operation of the Smart Feeder

19.12.2017 | https://www.orn.mpg.de | Copyright 2017 ©, MPIO Seewiesen | page 53

Charge time

The accumulators can be charged in roughly one day to ensure that the accumulators are securely fully-loaded.

Theoretically, a charging time of roughly 3 hours in both rechargers is enough for a complete loading.

The charging time at the IUoU can be marginally less, because the Uo phase at constant voltage with end-of-charge voltage can be higher than the CV voltage at the CCCV method.

### 7.5 Ah / 2A = 3.75 h

A discharged accumulator with 7.5 Ah requires a charging current of 2A for more than 3.75 hours, because the loading does not take place with a maximal current of 2A the whole time.

## Troubleshooting Smart Feeder

The current version of the Smart Feeder has taken three years of development. Some malfunctions could be encountered and thus lead to experience in troubleshooting and development of specific procedures for malfunctions which may be detected.

Troubleshooting in the field

The field troubleshooting takes place after a malfunction is detected through information from the data collected in the SD cards. Incorrect data indicates a malfunction at the Smart Feeder.

Troubleshooting in the laboratory

Via the LEUART-interface the Smart Feeder can be connected to a PC. This makes it possible to transfer information transmitted by the Microcontroller. This allows for a detailed view into the Smart Feeder.

If the failure cannot be detected via the LEUART-interface, the Smart Feeder has to be measured electronically for further troubleshooting.

Software

19.12.2017 | https://www.orn.mpg.de | Copyright 2017 ©, MPIO Seewiesen | page 54

## Software

The Software on the flash memory in the Multifunctional Mainboard to Observe and Manipulate Organisms is programmed with the programming language C. This software is diverse for different applications and has to be regenerated for every application. It needs to be smaller than 128 KB for the flash memory. The software for the Smart Feeder application will be described in this chapter. It includes reset options, the reset process, how data is stored and what occurs when the SD card is changed. Also described is how regular queries are stored, what can be done with the built-in buttons on the board and the possibility of software updates.

## Reset

The reset can be used to restart the system of the Multifunctional Mainboard to Observe and Manipulate Organisms when an unknown failure occurs. The procedure for a reset is always the same. The reset is a new start and can be compared with the start of a PC.

Possibilities to perform a manual reset

The Multifunctional Mainboard to Observe and Manipulate Organisms can be restarted manually in two ways:

- Via pushbutton
- Reset after electrical energy was not available for considerable time, so

that the capacitor could not provide enough energy. The capacitor has enough energy to provide MOMO for approx. 3 min.

Procedure after reset

After a reset the following procedure takes place:

### 1. Both LED’s (red and orange) will be illuminated to show that the hardware or

software is active and the LED’s are working.

Software

19.12.2017 | https://www.orn.mpg.de | Copyright 2017 ©, MPIO Seewiesen | page 55

Only visible in a terminal program on a PC.

### 2. In case a SD card is recognised, its data system is mounted and the free space

on the memory is displayed. This takes place at every exchange of SD cards during operation.

### 3. Afterwards it will be searched for a log file with the name “BOXnnnn.TXT” (nnnn

is a random decimal number). In the case that the file exists on the SD card the name will be displayed on the LC display otherwise the file “BOX0999.TXT” will be created.

Furthermore, the DCF77 module is switched on to receive date and time. The red LED now flashes to the rhythm of the radio clock signal.

4. After date and time got synchronized, the red LED switched off.

Reset protocol

If a start or a reset of the Multifunctional Mainboard to Observe and Manipulate Organisms is carried out some protocol lines are written on the SD card to com-prehend the process of the maintenance.

20140101-120000.000 DCF77: Enabled

20140101-120000.000 SD-Card Inserted

20140101-120000.054 SD-Card Initialized

20140101-120000.054 SD-Card File System mounted

20140101-120000.497 SD-Card 1938MB free

20140101-120000.499 Using Filename BOX0666.TXT

20140101-120000.517 MCU: EFM32G230F128 HW-ID: 0x245D670356B3C2C0

20140101-120000.550 Battery Manufacturer Name : | Dynamis
20140101-120000.576 Battery Manufacturer Data : | 61.90002/15790
20140101-120000.602 Battery Device Name | : | BMS2-4_V0.3
20140101-120000.629 Battery Device Type | : | Lithium-Ion
20140101-120000.636 Battery Serial Number | : 00008
20140101-120000.643 Battery Design Voltage | : 3.300V per cell

Software

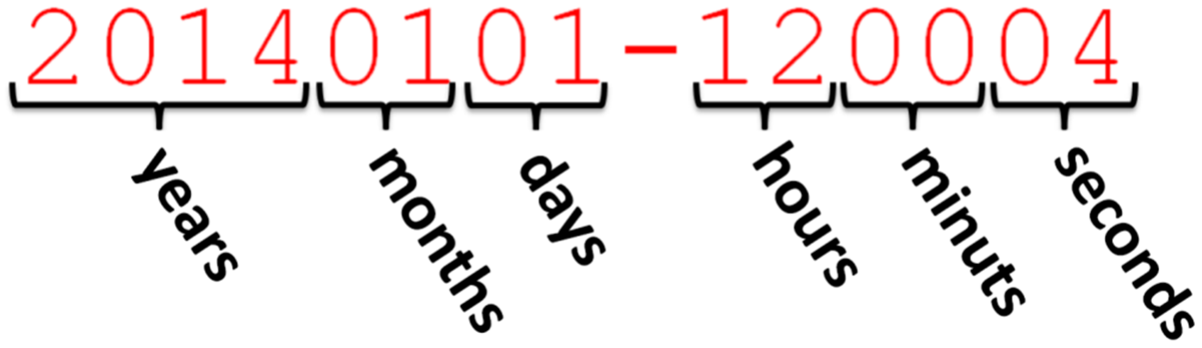
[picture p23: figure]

19.12.2017 | https://www.orn.mpg.de | Copyright 2017 ©, MPIO Seewiesen | page 56
20140101-120000.651 Battery Design Capacity | : 7500mAh

20140101-120000.658 Battery Full Charge Capac.: 8079mAh

20140101-120000.666 Battery Remaining Capacity: 7268mAh

20140101-120000.674 Battery Runtime to empty | : More than 6 weeks
20140101-120000.681 Battery Actual Voltage | : 13.3V
20140101-120000.689 Battery Actual Current | : | 0mA

20140101-120000.690 Reading Configuration File CONFIG.TXT

## Data storage

All important information from the RAM memory will be saved in a txt-file on the SD card. Every event or stored message begins with the date and time of the event.

Following the date and time there is a blank space. Then follows the actual status message.

Procedure after SD card change

After a new SD card is plugged in the following procedure starts.

1. It displays that a new SD card has been detected.

20140101-120004 SD-Card Inserted

20140101-120004 SD-Card Initialized

20140101-120004 SD-Card File System mounted

Software

19.12.2017 | https://www.orn.mpg.de | Copyright 2017 ©, MPIO Seewiesen | page 57
2. The following line shows how much free space remains on the SD card.

20140101-120011 SD-Card 1880MB free

### 3. Afterwards it will search for a log file with the name „BOXnnnn.TXT“ (nnnn is a

random decimal number). In case that the file exists on the SD card the name will be displayed on the LC display otherwise the file „BOX0999.TXT“ will be created.

20140101-120011 Using Filename BOX0999.TXT

20140101-120011 Media Change: BOX0999.TXT -> BOX0020.TXT

### 4. The hardware ID will be displayed, which is a unique number allocated to each

Multifunctional Mainboard to Observe and Manipulate Organisms

20140101-120011 MCU: EFM32G230F128 HW-ID: 0x24B4010253FD82EE

### 5. The status of the accumulator is then displayed, including the manufacturer

name, manufacturer data, device name, device type, serial number, design voltage, design capacity, total capacity, remaining capacity, remaining time at actual current and at least the measured actual voltage.

20140101-120011 Battery Manufacturer Name : | Dynamis
20140101-120011 Battery Manufacturer Data : | 61.90002/15790
20140101-120011 Battery Device Name | : | BMS2-4_V0.3
20140101-120011 Battery Device Type | : | Lithium-Ion
20140101-120011 Battery Serial Number | : 00008
20140101-120011 Battery Design Voltage | : 3.300V per cell
20140101-120012 Battery Design Capacity | : 7500mAh

20140101-120012 Battery Full Charge Capac.: 8968mAh

20140101-120012 Battery Remaining Capacity: 4122mAh

20140101-120012 Battery Runtime to empty | : More than 6 weeks
20140101-120012 Battery Actual Voltage | : 13.149V
20140101-120012 Battery Actual Current | : | 3mA

Software

19.12.2017 | https://www.orn.mpg.de | Copyright 2017 ©, MPIO Seewiesen | page 58

### 6. The configuration file CONFIG.txt is read. This process enables the

manipulation of the different identities. Up to 52 identities can be programed. A detailed description can be found in the CONFIG.txt file. Attention should be paid to further settings of energy-saving times, light barrier logic for known birds, animal transponder readers, switching off time and transponder identification for unknown identities (UNKNOWN). Standard stocks for flaps and cameras.

20140101-120000.690 Reading Configuration File CONFIG.TXT

ON_TIME | : 03:35
OFF_TIME | : 22:40
LB_FILTER_DURATION | : 10

RFID_PWR_OFF_TIMEOUT : 360

RFID_DETECT_TIMEOUT | : 15
KEEP_OPEN | : 60
KEEP_CLOSED | : 120
CAM1_DURATION | : 15

: KEEP_OPEN : KEEP_CLOSED : CAM1_DURATION

108196A801AF0001 | : | 180 | : | default | : | default
9E1CE7D001AF0001 | : | ALWAYS | : | default | : | default
ANY | : | 120 | : | 240 | : | 360
D5CD24B43A6F0001 | : | ALWAYS | : | default | : | default

### 7. The time of the microcontroller is updated through the signals from the radio

clock. This process usually only takes a few minutes.

20140101-120856 DCF77: Time Frame 1 is 20160315-143100

20140101-120956 DCF77: Time Frame 2 is 20160315-143200

20160315-143200 Initial Time Synchronisation

20160315-143200 DCF77: Time Synchronization 14:32:00

20160315-143200 DCF77: Disabled

Software

19.12.2017 | https://www.orn.mpg.de | Copyright 2017 ©, MPIO Seewiesen | page 59

## Periodic routine queries

Time update

Every 24 hours, during the night the time from the microcontroller is updated by the signals from the radio clock.

20170304-015500.000 DCF77: Enabled

20170304-015659.279 DCF77: Time Frame 1 is 20170304-015700

20170304-015759.283 DCF77: Time Frame 2 is 20170304-015800

20170304-015800.284 DCF77: Time Synchronization 01:58:00 (MEZ)

20170304-015800.001 DCF77: Disabled

Further outputs:

Log ("DCF77: Changing time zone from MEZ to MESZ");

Log ("DCF77: Changing time zone from MESZ to MEZ”);

If the DCF77 is not connected, there is no sync signal and no synchronisation.

Battery status query

At 11 a.m. and 11 p.m. the battery status is written on the memory as well as on the SD card. In addition, the current power demand is calculated. The range of the accumulator is calculated from data taken from the accumulator board. The remaining capacity and the current power demand are used for the calculation of the remaining range.

20170303-230000.014 Battery Remaining Capacity: 7271mAh

20170303-230000.021 Battery Runtime to empty | : More than 6 weeks
20170303-230000.029 Battery Actual Voltage | : 13.3V
20170303-230000.036 Battery Actual Current | : | 0mA

Software

19.12.2017 | https://www.orn.mpg.de | Copyright 2017 ©, MPIO Seewiesen | page 60

## Recorded events

One task of the Multifunctional Mainboard to Observe and Manipulate Organisms is to record the behaviour of animals. In the Smart Feeder application this is achieved via recordings from the light barrier activity and transponder detections as well as via the closing of the shutter.

Light barrier activity

The light barriers are always active and are always supplied with electrical energy. They are the trigger for the RFID Reader which is by far the largest energy consumer.

20160323-112408 LBO:ON | # Light barrier outer on
20160323-112408 LBI:ON | # Light barrier inner on
20160323-112408 LBO:off | # Light barrier outer off
20160323-112408 LBI:off | # Light barrier inner off

Transponder activity

The RFID reader is switched on by light barrier activity. This needs to occur very quickly as the transponder may be rapidly moving through the barrier and its number needs to be read completely. The birds have a particularly high velocity when approaching, which is why the RFID Reader needs to be activated very quickly.

20150723-154010 RFID is powered ON

20150723-154010 Transponder: D5CD24B43A6F0001

20150723-154122 RFID is powered off

Because it is likely to detect further activity after a transponder is detected, the RFID remains on for an additional 6 minutes after the last transponder signal.

Software

19.12.2017 | https://www.orn.mpg.de | Copyright 2017 ©, MPIO Seewiesen | page 61

Servomotor activity

The servomotor is closed or opened after the query of the CONFIG.txt file. .

20170317-114613.295 Shutter will be opened

20170317-114528.437 Shutter will be closed

Connections for possible recording devices (camera)

20170317-105658.000 CAM1 is powered on

20170317-105758.000 CAM1 is powered off

20170317-105658.000 CAM2 is powered on

20170317-105758.000 CAM2 is powered off

Standard recording

In the following there are typical status messages:

20170317-112428.223 LB1:ON

20170317-112428.223 CAM1 is powered ON

20170317-112428.224 RFID is powered ON

20170317-112428.584 Transponder: 0B6122B43A6F0001:0:A:15

20170317-112428.585 Shutter will be closed

20170317-112428.823 LB1:off

20170317-112428.823 LB1:off

20170317-112452.000 CAM1 is powered off

20170317-113038.000 RFID is powered off

Software

19.12.2017 | https://www.orn.mpg.de | Copyright 2017 ©, MPIO Seewiesen | page 62

Power Good and Power Fail

- Battery gets disconnected
- Power fail gets detected
- RFID Reader and CAM1 get switched off
- Battery gets reconnected
- normal function without reset, RFID Reader and CAM1 get reactivated on demand

4/18/2017 12:45:06.274 [RX] - 20170418-124506.221 Power-Fail: Received interrupt (POWER FAIL)

4/18/2017 12:51:44.342 [RX] - 20170418-125144.296 LB1:ON

20170418-125144.402 LB2:ON

4/18/2017 12:51:45.030 [RX] - 20170418-125144.985 LB1:off

20170418-125144.986 LB2:off

4/18/2017 12:53:59.514 [RX] - 20170418-125359.436 Power-Fail: Received interrupt (POWER GOOD)

Software

19.12.2017 | https://www.orn.mpg.de | Copyright 2017 ©, MPIO Seewiesen | page 63

## Occurrences when it is not possible to write on the SD card

When the SD card is full or if there is no SD card is in SD card slot an error message is written on the LEUART-BUS. During a normal operation of the Smart Feeder application of the Multifunctional Mainboard to Observe and Manipulate Organisms, it is not common that data is lost due to an absent or malfunctioning SD card, because the internal memory for events provides 2 KB, which should be sufficient for many events to be stored.

ERROR: Log Buffer Out of Memory - lost 1 Messages (only appears on
HyperTerminal screen of the PC)

More error messages:

ERROR Config File - Line 131, pos 26, ID: OUT OF MEMORY

SMB_Reset: Try to recover from invalid state

SMB_Reset: Recovery failed, giving up

CfgRead: FILE OPEN - Error Code

CfgRead: FILE READ - Error Code

CfgRead: Line %d too long

Config File - Line %d, pos %ld: Invalid Variable Name

Config File - Line %d, pos %ld: Unknown Variable

Config File - Line %d, pos %ld: Unknown Variable

Config File - Line %d, pos %ld: Value expected

Config File - Line %d, pos %ld, %s: Invalid time

Config File - Line %d, pos %ld, %s: OUT OF MEMORY

Config File - Line %d, pos %ld, %s: Unsupported data type

Config File - Line %d, pos %ld: Garbage at end of line

LogError ("LogFileOpen: Error Code %d", res);

See if Log File is open */

LogError ("LogFlush: Init Failed");

LogError ("LogFlush: Error Code %d", res);

LogError ("LogFlush: Disk Full");

Expiry after keystroke

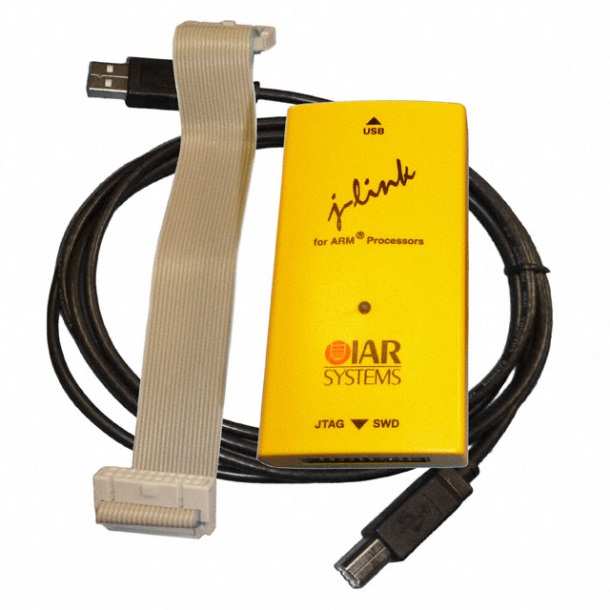
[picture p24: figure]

19.12.2017 | https://www.orn.mpg.de | Copyright 2017 ©, MPIO Seewiesen | page 64

## Expiry after keystroke

The Multifunctional Mainboard to Observe and Manipulate Organisms contains a button for conducting a reset.

After pressing the S1 button, the whole system will be restarted. The procedure of the restart is described in chapter Fehler! Verweisquelle konnte nicht gefunden werden..

## Update options

There are three possibilities to write software code on the flash memory.
The method of the Debug Probe and the one via the Debug Interface always work. If software was written on the flash memory via either one of these the methods examining the content of a newly inserted SD card and searching for software updates, a third method can be implemented.

## IAR Systems Debug Probe

Through the debug probe from IAR systems it is possible to load compiled software code on the flash memory. The software from IAR for the debug probe is necessary for this.

IAR Systems also distribute the software IAR Embedded Workbench to create and compile C code. The compiled C code can be loaded on the flash memory by the debug probe.

Expiry after keystroke

19.12.2017 | https://www.orn.mpg.de | Copyright 2017 ©, MPIO Seewiesen | page 65

## With USB on 10-pole Debug Interface Connector

This method only allows HEX and BIN files to be transferred to the flash memory and has the benefit of the original C code not being readable anymore.

## Via SD card and boot loader

If software has already been written on the flash memory by either of the methods from chapter 7.2 or 7.3 a third method through a boot loader is available. If the software of the flash memory contains the command to search for new software when recognizing a new SD card, this new software can be installed.

Contact details

19.12.2017 | https://www.orn.mpg.de | Copyright 2017 ©, MPIO Seewiesen | page 66

## Contact details

address | Max-Planck-Institut für Ornithologie Eberhard-Gwinner-Str. 82319 Seewiesen
web address | http://www.orn.mpg.de/
electronics developer | Dipl. Ing. (FH) Peter Loës
e-mail address | loes@orn.mpg.de
telephone number | Tel: +49 8157 932-330

Links to the datasheets

19.12.2017 | https://www.orn.mpg.de | Copyright 2017 ©, MPIO Seewiesen | page 67

## 8. Links to the datasheets

Datasheets need to be saved within the folder ‘datasheets’, which has to be in the same content as the documentation. For every link there is a document within this folder.

EFM32G230

IAR J Tag ARM

LC display

SD card reader

Button

Capacitor

Jack connector

USB cable

Down converter

LED’S

Radio clock

Light barrier

RFID reader

RFID transponder

Housing for the main board

Housing for the accumulator

Battery charger Fronius

Battery charger Mascot

Battery cell

Content

19.12.2017 | https://www.orn.mpg.de | Copyright 2017 ©, MPIO Seewiesen | page 68

## Content

Connections for switchable power supplies for three RFID reading

Content

19.12.2017 | https://www.orn.mpg.de | Copyright 2017 ©, MPIO Seewiesen | page 69

Technical description of additional connectivity options for applications 35

Content

19.12.2017 | https://www.orn.mpg.de | Copyright 2017 ©, MPIO Seewiesen | page 70

Content

19.12.2017 | https://www.orn.mpg.de | Copyright 2017 ©, MPIO Seewiesen | page 71

Content

19.12.2017 | https://www.orn.mpg.de | Copyright 2017 ©, MPIO Seewiesen | page 72

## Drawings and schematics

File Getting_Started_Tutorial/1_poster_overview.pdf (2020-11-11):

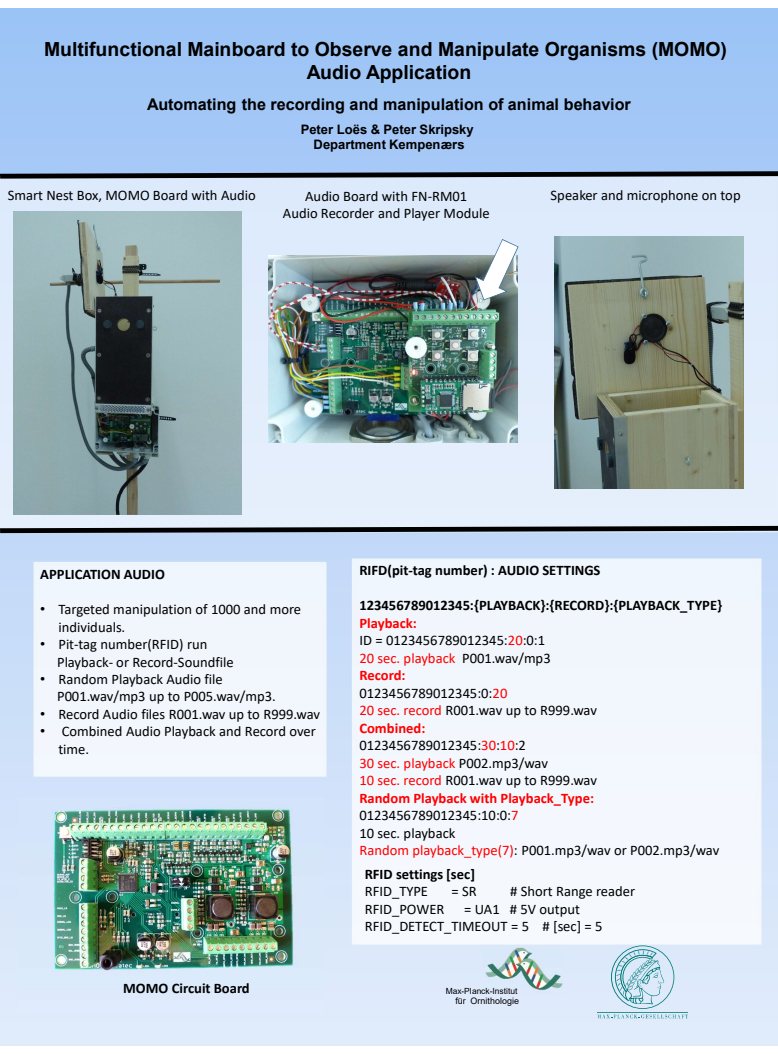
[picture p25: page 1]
Audio Application; RFID_TYPE; # Short Range reader; APPLICATION AUDIO; Smart Nest Box, MOMO Board with Audio; Audio Board with FN-RM01

Multifunctional Mainboard to Observe and Manipulate Organisms (MOMO)

Automating the recording and manipulation of animal behavior

Peter Loës & Peter Skripsky
Department Kempenærs

Speaker and microphone on top

Audio Recorder and Player Module

RIFD(pit-tag number) : AUDIO SETTINGS

123456789012345:{PLAYBACK}:{RECORD}:{PLAYBACK_TYPE}
Playback:
20 sec. playback P001.wav/mp3
Record:
20 sec. record R001.wav up to R999.wav
Combined:
30 sec. playback P002.mp3/wav
10 sec. record R001.wav up to R999.wav
Random Playback with Playback_Type:
10 sec. playback
Random playback_type(7): P001.mp3/wav or P002.mp3/wav
RFID settings [sec]
RFID_POWER = UA1 # 5V output
RFID_DETECT_TIMEOUT = 5 # [sec] = 5

• Targeted manipulation of 1000 and more
individuals. • Pit-tag number(RFID) run

Playback- or Record-Soundfile
• Random Playback Audio file
P001.wav/mp3 up to P005.wav/mp3. • Record Audio files R001.wav up to R999.wav

• Combined Audio Playback and Record over
time.

MOMO Circuit Board

Max-Planck-Institut
für Ornithologie

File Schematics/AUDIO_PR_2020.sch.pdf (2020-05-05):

# Power Input

# Audio Play Recorder Module

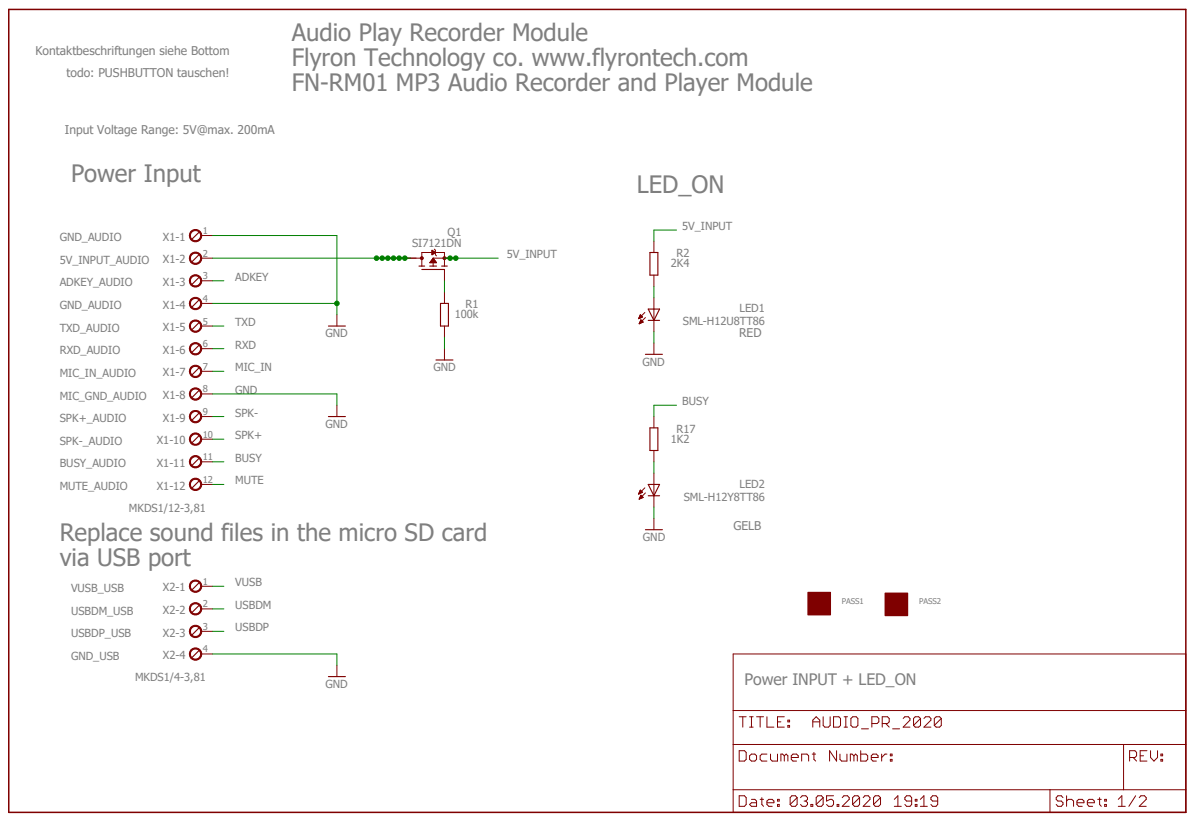
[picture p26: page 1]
Power INPUT + LED_ON; LED_ON; RED; GELB; SML-H12U8TT86; GND; MKDS1/4-3,81; MKDS1/12-3,81; SML-H12Y8TT86; GND_AUDIO; 5V_INPUT_AUDIO; ADKEY_AUDIO; TXD_AUDIO; RXD_AUDIO; MIC_IN_AUDIO; MIC_GND_AUDIO; SPK+_AUDIO; SPK-_AUDIO; BUSY_AUDIO; VUSB_USB; USBDM_USB; USBDP_USB; GND_USB; LED1; PASS1; PASS2; LED2; 5V_INPUT; SPK-; TXD; ADKEY; RXD; MIC_IN; BUSY; VUSB; USBDM; USBDP; MUTE; SPK+

Kontaktbeschriftungen siehe Bottom

Flyron Technology co. www.flyrontech.com
FN-RM01 MP3 Audio Recorder and Player Module

todo: PUSHBUTTON tauschen!

Input Voltage Range: 5V@max. 200mA

MUTE_AUDIO
Replace sound files in the micro SD card
via USB port

# FN-RM01 MP3 Module

## SD Karten Slot

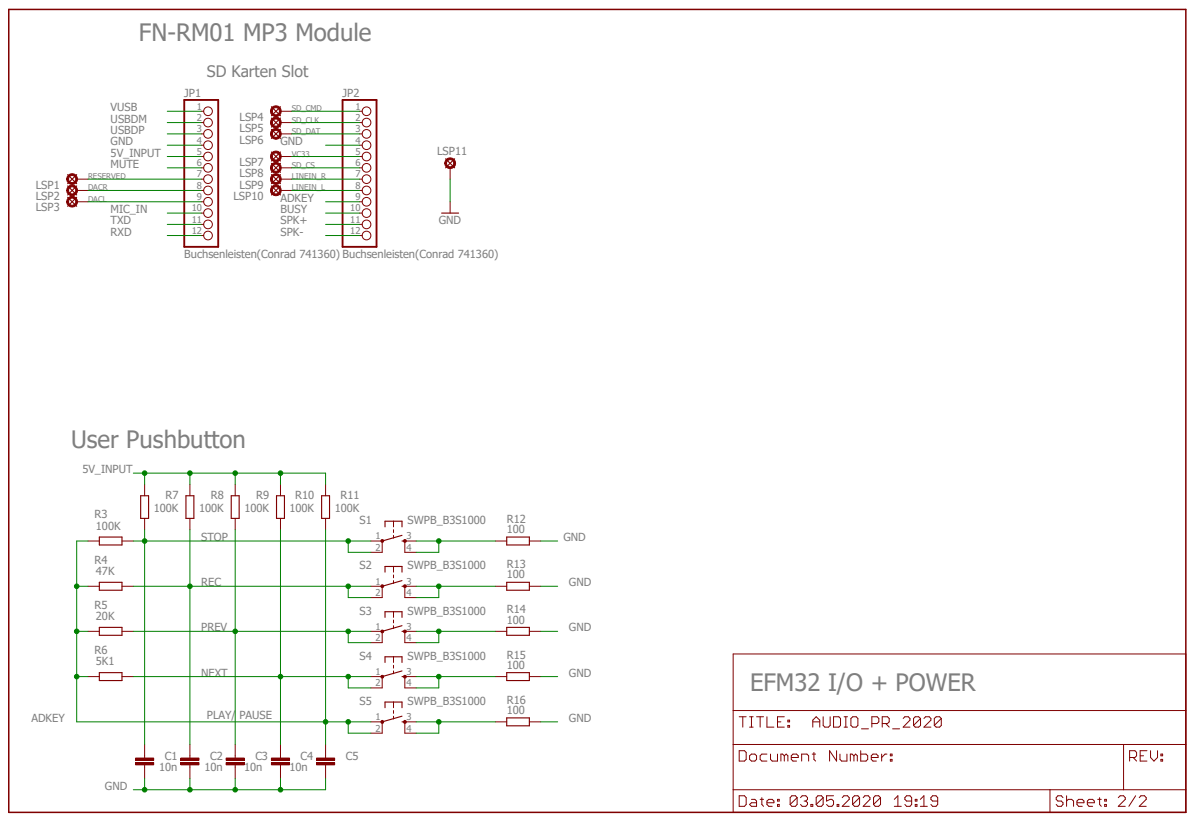
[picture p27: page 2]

Buchsenleisten(Conrad 741360)

NEXT

PLAY/ | PAUSE | SWPB_B3S1000

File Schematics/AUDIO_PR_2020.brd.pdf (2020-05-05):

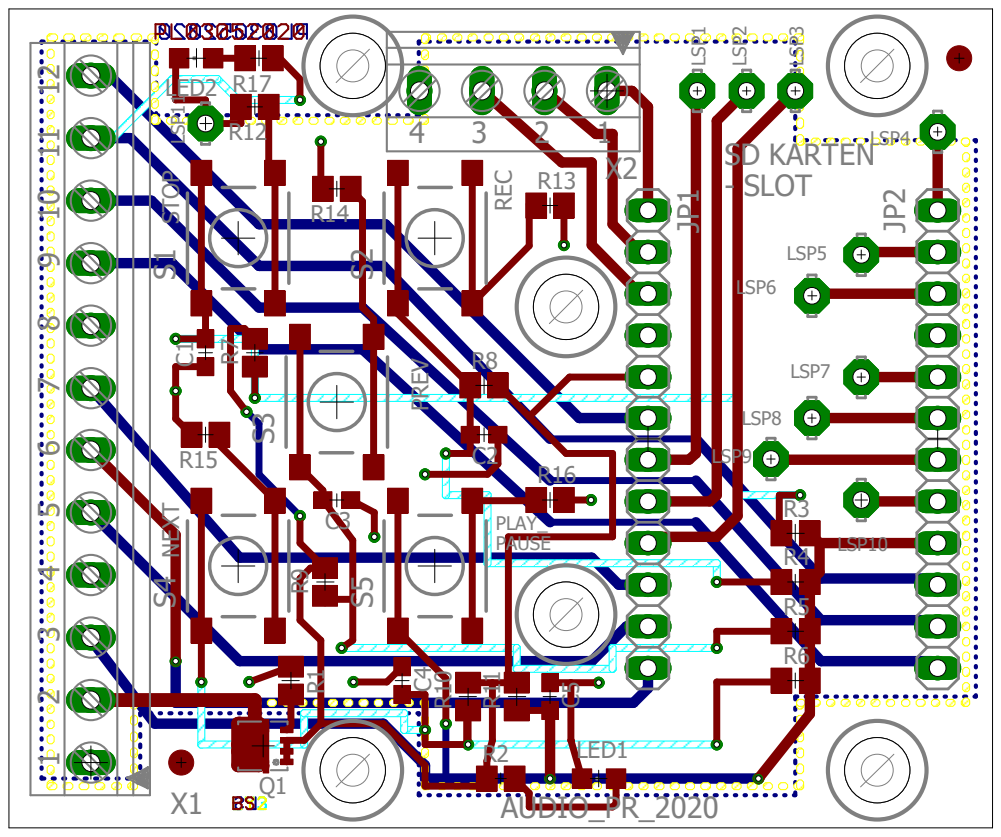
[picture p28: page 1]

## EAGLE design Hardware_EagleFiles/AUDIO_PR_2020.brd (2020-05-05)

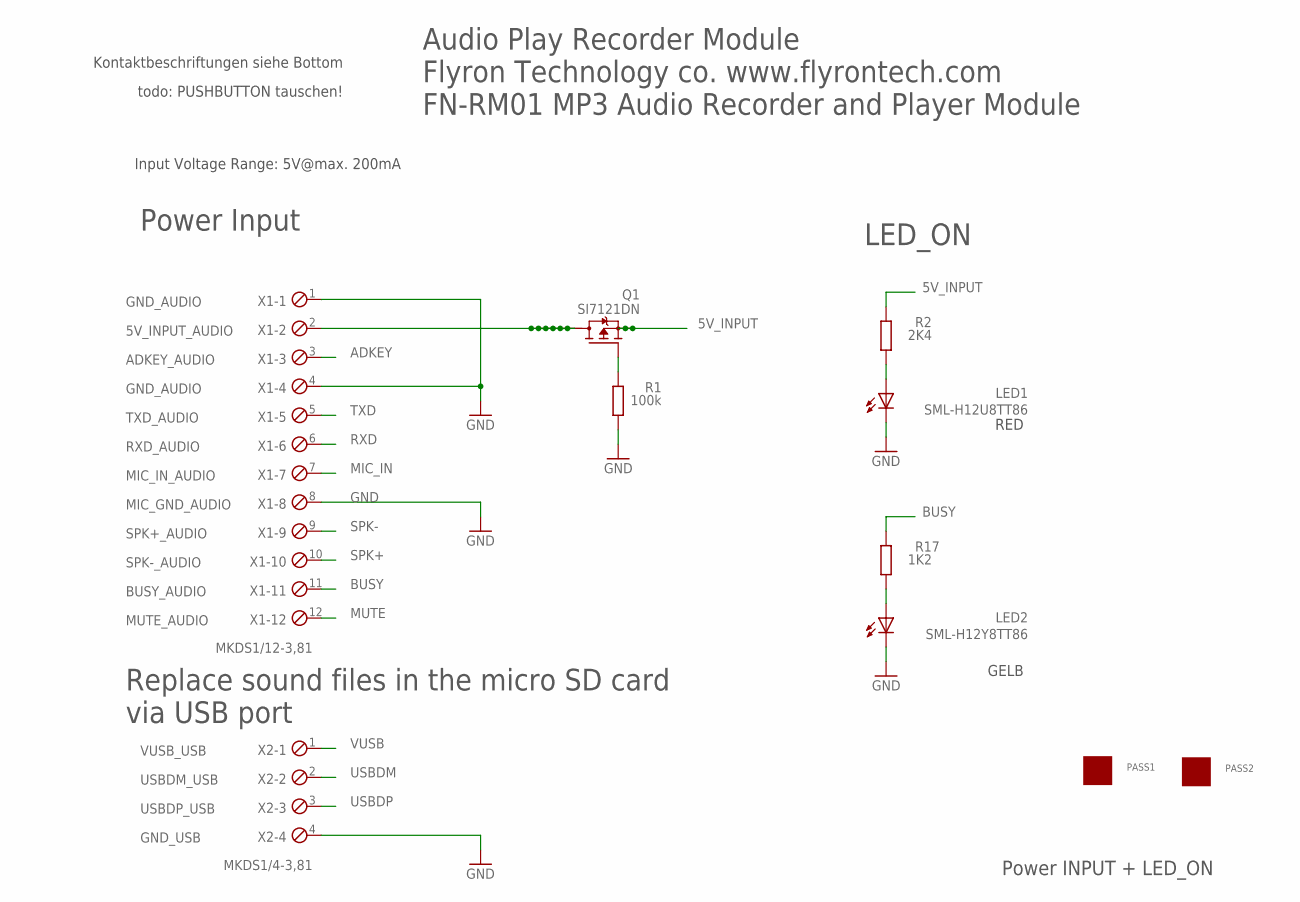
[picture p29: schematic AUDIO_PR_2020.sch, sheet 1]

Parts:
LED1: SML-H12U8TT86; CHIPLED_0805
LED2: SML-H12Y8TT86; CHIPLED_0805
PASS1, PASS2: ROUND_1MM1.5; ROUND2_1.5MM
Q1: SI7121DN; TRANSISTOR-FET_1212-8S
R1: 100k; R0805
R2: 2K4; R0805
R17: 1K2; R0805
X1: MKDS1/12-3,81; 12POL381
X2: MKDS1/4-3,81; 4POL381

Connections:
5V_INPUT: Q1.1 (S), Q1.2 (S), Q1.3 (S), R2.1; also elsewhere on the board
5V_INPUT_AUDIO: Q1.5 (D), Q1.6 (D), Q1.7 (D), Q1.8 (D), Q1.9 (D), Q1.10 (D), Q1.11 (D), X1.2
ADKEY: X1.3; also elsewhere on the board
BUSY: R17.1, X1.11; also elsewhere on the board
GND: LED1.C, LED2.C, R1.1, X1.1, X1.4, X1.8, X2.4; also elsewhere on the board
MIC_IN: X1.7; also elsewhere on the board
MUTE: X1.12; also elsewhere on the board
unnamed: LED2.A, R17.2
unnamed: Q1.4 (G), R1.2
unnamed: LED1.A, R2.2
RXD: X1.6; also elsewhere on the board
SPK+: X1.10; also elsewhere on the board
SPK-: X1.9; also elsewhere on the board
TXD: X1.5; also elsewhere on the board
USBDM: X2.2; also elsewhere on the board
USBDP: X2.3; also elsewhere on the board
VUSB: X2.1; also elsewhere on the board

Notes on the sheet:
GND_AUDIO
Input Voltage Range: 5V@max. 200mA
5V_INPUT_AUDIO
Power INPUT + LED_ON
Power Input
Audio Play Recorder Module Flyron Technology co. www.flyrontech.com FN-RM01 MP3 Audio Recorder and Player Module
LED_ON
RED
ADKEY_AUDIO
TXD_AUDIO
RXD_AUDIO
MIC_IN_AUDIO
MIC_GND_AUDIO
SPK+_AUDIO
SPK-_AUDIO
BUSY_AUDIO
VUSB_USB
USBDM_USB
USBDP_USB
GND_USB
Replace sound files in the micro SD card via USB port
MUTE_AUDIO
Kontaktbeschriftungen siehe Bottom
todo: PUSHBUTTON tauschen!
GELB

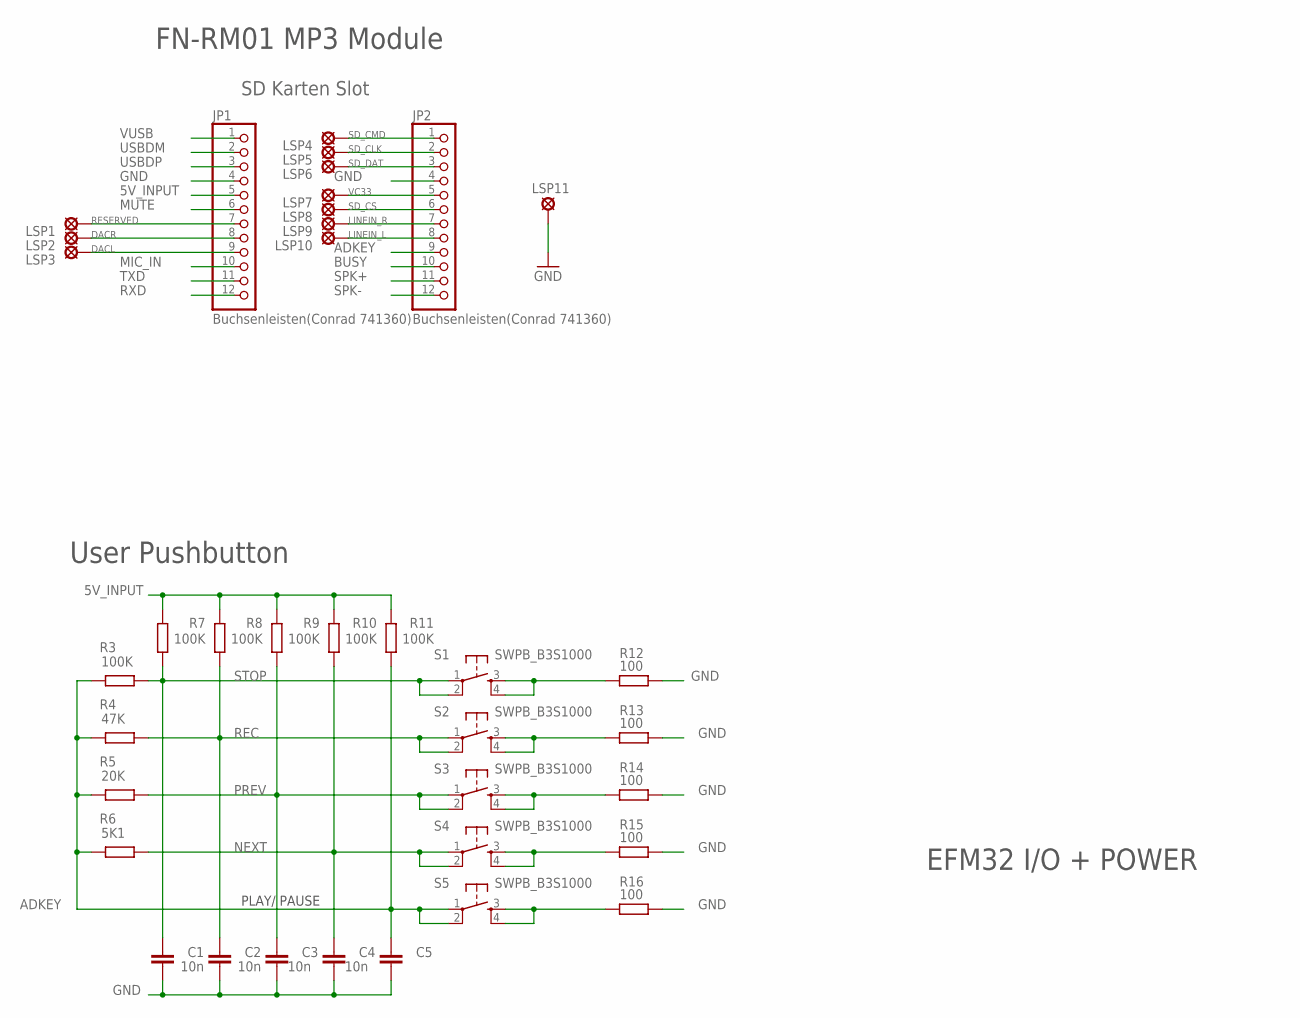
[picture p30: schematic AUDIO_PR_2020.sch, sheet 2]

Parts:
C1, C2, C3, C4, C5: 10n; C0603
JP1, JP2: Buchsenleisten(Conrad 741360); 1X12
LSP1, LSP2, LSP3, LSP4, LSP5, LSP6, LSP7, LSP8, LSP9, LSP10, LSP11: LSP10
R3, R7, R8, R9, R10, R11: 100K; R0805
R4: 47K; R0805
R5: 20K; R0805
R6: 5K1; R0805
R12, R13, R14, R15, R16: 100; R0805
S1, S2, S3, S4, S5: SWPB_B3S1000; DTSM-6

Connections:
5V_INPUT: JP1.5, R7.2, R8.2, R9.2, R10.2, R11.2; also elsewhere on the board
ADKEY: C5.2, JP2.9, R3.2, R4.2, R5.2, R6.2, R11.1, S5.1, S5.2; also elsewhere on the board
BUSY: JP2.10; also elsewhere on the board
DACL: JP1.9, LSP3.MP
DACR: JP1.8, LSP2.MP
GND: C1.1, C2.1, C3.1, C4.1, C5.1, JP1.4, JP2.4, LSP11.MP, R12.2, R13.2, R14.2, R15.2, R16.2; also elsewhere on the board
LINEIN_L: JP2.8, LSP10.MP
LINEIN_R: JP2.7, LSP9.MP
MIC_IN: JP1.10; also elsewhere on the board
MUTE: JP1.6; also elsewhere on the board
unnamed: R14.1, S3.3, S3.4
unnamed: R15.1, S4.3, S4.4
unnamed: R16.1, S5.3, S5.4
unnamed: R12.1, S1.3, S1.4
unnamed: R13.1, S2.3, S2.4
NEXT: C4.2, R6.1, R10.1, S4.1, S4.2
PREV: C3.2, R5.1, R9.1, S3.1, S3.2
REC: C2.2, R4.1, R8.1, S2.1, S2.2
RESERVED: JP1.7, LSP1.MP
RXD: JP1.12; also elsewhere on the board
SD_CLK: JP2.2, LSP5.MP
SD_CMD: JP2.1, LSP4.MP
SD_CS: JP2.6, LSP8.MP
SD_DAT: JP2.3, LSP6.MP
SPK+: JP2.11; also elsewhere on the board
SPK-: JP2.12; also elsewhere on the board
STOP: C1.2, R3.1, R7.1, S1.1, S1.2
TXD: JP1.11; also elsewhere on the board
USBDM: JP1.2; also elsewhere on the board
USBDP: JP1.3; also elsewhere on the board
VC33: JP2.5, LSP7.MP
VUSB: JP1.1; also elsewhere on the board

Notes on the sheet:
EFM32 I/O + POWER
User Pushbutton
SD Karten Slot
FN-RM01 MP3 Module
PLAY/ PAUSE

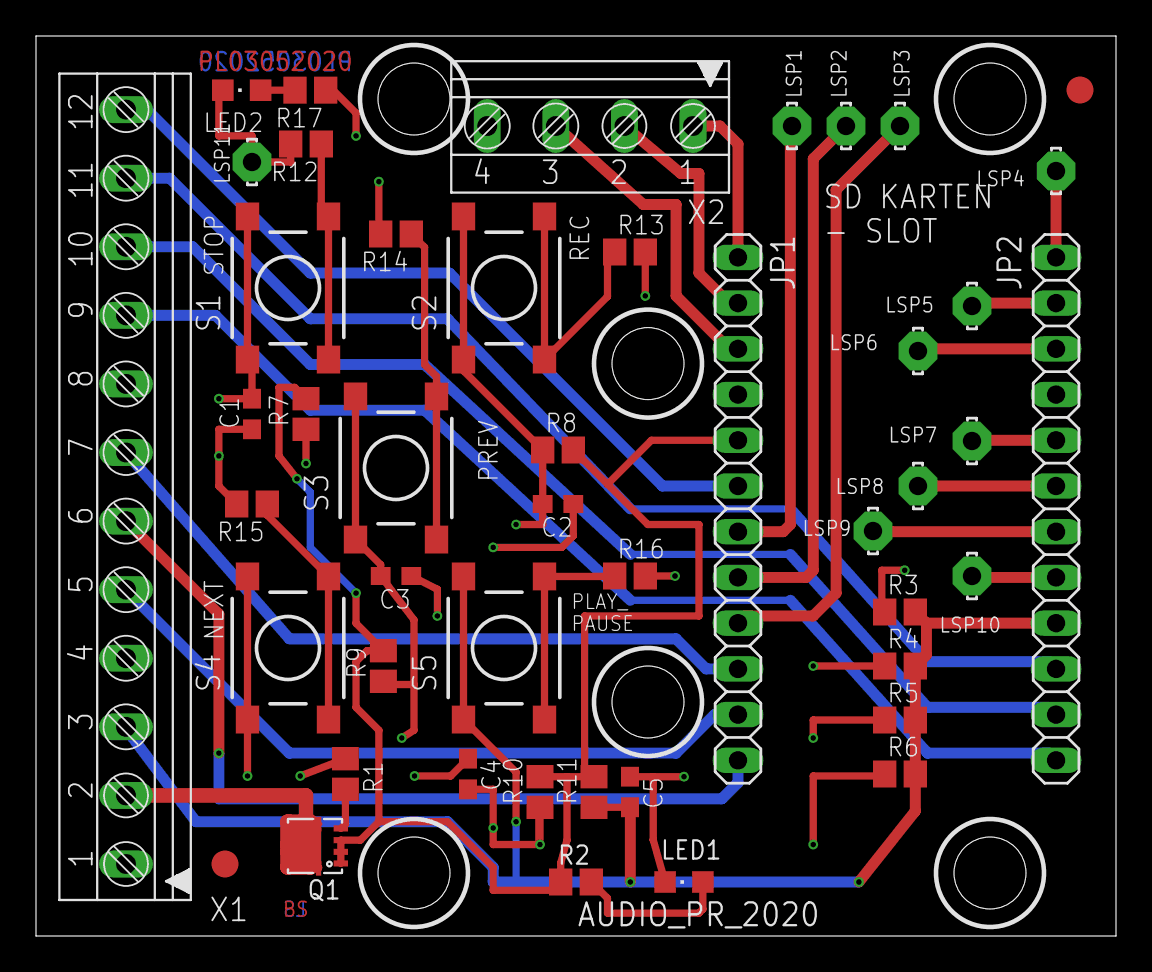
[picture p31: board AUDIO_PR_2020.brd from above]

Board: 4 copper layers, 60.0 x 50.0 mm, 47 parts (0 on the bottom side), 36 nets.

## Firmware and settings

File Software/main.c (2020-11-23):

/***************************************************************************//**
 * @file
 * @brief	MOMO_AUDIO
 * @author	Ralf Gerhauser / Peter Loes 
 * @version	2020-07-17
 *
 * This application consists of the following modules:
 * - main.c - Initialization code and main execution loop.
 * - DMA_ControlBlock.c - Control structures for the DMA channels.
 * - Control.c - Sequence Control module.
 * - CfgData.c - Handling of configuration data.
 * - ExtInt.c - External interrupt handler.
 * - AlarmClock.c - Alarm clock and timers facility.
 * - DCF77.c - DCF77 Atomic Clock Decoder
 * - clock.c - An implementation of the POSIX time() function.
 * - LightBarrier.c - Interrupt logic for the two light barriers,
 *   enables the RFID reader.
 * - RFID.c - RFID reader to receive transponder IDs.
 * - Audio.c - Audio Module to play and record animal sounds.
 * - BatteryMon.c - Battery monitor, periodically reads the state of the
 *   battery via the SMBus.
 * - LEUART.c - The Low-Energy UART can be used as monitoring and debugging
 *   connection to a host computer.
 * - microsd.c - Together with the files "diskio.c" and "ff.c", this module
 *   provides an implementation of a FAT file system on the @ref SD_Card.
 * - Logging.c - Logging facility to send messages to the LEUART and store
 *   them into a file on the SD-Card.
 * - PowerFail.c - Handler to switch off all loads in case of Power Fail.
 *
 * Parts of the code are based on the example code of AN0006 "tickless calender"
 * from Energy Micro AS.
 *
 ***************************************************************************//**
 *
 * Parts are Copyright 2013 Energy Micro AS, http://www.energymicro.com
 *
 *******************************************************************************
 *
 * Permission is granted to anyone to use this software for any purpose,
 * including commercial applications, and to alter it and redistribute it
 * freely, subject to the following restrictions:
 *
 * 1. The origin of this software must not be misrepresented; you must not
 *    claim that you wrote the original software.
 * 2. Altered source versions must be plainly marked as such, and must not be
 *    misrepresented as being the original software.
 * 3. This notice may not be removed or altered from any source distribution.
 * 4. The source and compiled code may only be used on Energy Micro "EFM32"
 *    microcontrollers and "EFR4" radios.
 *
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
 * Energy Micro AS will not be liable for any consequential, incidental, or
 * special damages, or any other relief, or for any claim by any third party,
 * arising from your use of this Software.
 *
 ****************************************************************************//*
Revision History:
2020-07-17,rage - Audio Module expansion
2020-05-12,rage	- Call CheckAlarmTimes() after CONFIG.TXT has been read.
2019-06-20,rage	- Moved DMA related variables to module "DMA_ControlBlock.c".
		- Report available memory (debug version only).
2019-05-24,rage	- Used basic logic from project TAMDL.
2017-11-07,Loes	- Initial version for MOMO, derived from MAPRDL.
*/

/*!
 * @mainpage
 * @section desc Description
 * MOMO_AUDIO is an application to control a Audio Module via transponder ID.
 * It consists of the following components.
 *
 * @subsection ssa00 Memory Map
 * FLASH and SRAM memory ranges:
 * <center><table>
 * <tr><th>Address</th> <th>Description</th></tr>
 * <tr><td>0x00000000</td> <td>Start of FLASH, here resides the Booter (32KB)</td></tr>
 * <tr><td>0x00008000</td> <td>Start of Application Software (up to 88KB)</td></tr>
 * <tr><td>0x0001FFFF</td> <td>End of 128KB FLASH</td></tr>
 * <tr><td>0x10000000</td> <td>Start of SRAM when accessed as Code</td></tr>
 * <tr><td>0x10003FFF</td> <td>End of 16KB SRAM when accessed as Code</td></tr>
 * <tr><td>0x20000000</td> <td>Start of SRAM when accessed as Data</td></tr>
 * <tr><td>0x20003FFF</td> <td>End of 16KB SRAM when accessed as Data</td></tr>
 * </table></center>
 *
 * @subsection ssa01 Microcontroller
 * The heart of the board is an EFM32G230 microcontroller.  It provides two
 * different clock domains: All low-energy peripheral is clocked via a
 * 32.768kHz external XTAL.  The MCU and other high performance peripheral
 * uses a high-frequency clock.  The board can be configured to use the
 * internal RC-oscillator, or an external 32MHz XTAL for that purpose,
 * see define @ref USE_EXT_32MHZ_CLOCK.
 *
 * @subsection DCF77_Atomic_Clock DCF77 Atomic Clock
 * When powered on, the DCF77 hardware module is enabled to receive the time
 * information and set the system clock.  During this phase, the Power-On LED
 * (i.e. LED1) shows the current state of the DCF signal.  The further behavior
 * depends on the settings in the <i>config.h</i> file.  If the define @ref
 * DCF77_ONCE_PER_DAY is 1, the receiver (and also the LED) will be switched
 * off after time has been synchronized.  As the name of the define suggests,
 * it will be switched on once per day.  To properly detect a change between
 * winter and summer time, i.e. <i>normal time</i> (MEZ) and <i>daylight saving
 * time</i> (MESZ), this happens at 01:55 for MEZ, and 02:55 for MESZ.<br>
 * If the define is 0, the receiver remains switched on, but the LED will only
 * get active again when the time signal gets out-of-sync.<br>
 *
 * @subsection ssa03 Light Barriers
 * The firmware supports two light barriers, one is used to detect
 * a bird near the Smart Nest Box.
 *
 * @subsection RFID_Reader RFID Reader
 * The RFID reader is used to receive the transponder number of the bird.
 * The module can be configured as Short Range (SR) or Long Range (LR) reader
 * via configuration variable @ref RFID_TYPE.  The reader hardware is supplied
 * by one of the @ref Power_Outputs.  Use variable @ref RFID_POWER to select the
 * right one.  Be sure to verify the output voltage is correct, otherwise
 * the reader may be destroyed.<br>
 * The RFID reader is enabled by the ON-Times, and disabled by the respective
 * OFF-Times.  If a transponder ID has been detected, it is logged to a file
 * on the @ref SD_Card.  If the configuration variable @ref
 *
 * @subsection ssa05 MomoAudio 
 * This is one of the key elements of the system.  
 * It is powered ON or OFF via alarm_times ON_TIME_1~5, OFF_TIME_1~5.
 * The default values of the timeout defines above may be overwritten by the
 * variables in <a href="../../CONFIG.TXT"><i>CONFIG.TXT</i></a>.
 * MomoAudio alarm_times include the POWER from RFID Reader and AUDIO Module.
 *
 * @subsection ssa06 AUDIO Audio
 * The Audio Module is playback and record sounds via transponder ID.
 * Audio handles automatic the FN-RM01 MP3 Audio Recorder and Playback Module.
 *
 * @subsection ssa07 LEDs
 * There are two LEDs, one is red, the other one is green.
 * - The red LED is the Power-On LED.  It shows the current state of the
 *   DCF77 signal during receiving of the time information.  In normal
 *   condition the LED will be switched off.
 * - The green LED is the Log Flush LED.  It flashes whenever there are write
 *   accesses to SD-Card.
 *
 * @subsection ss8 SD-Card
 * The SD-Card is used to store configuration and logging data.  Only formatted
 * cards can be used, supported file systems are FAT12, FAT16, and FAT32.  The
 * filenames must follow the DOS schema 8+3, i.e. maximum 8 characters for
 * the basename, and 3 for the extension.  If the SD-Card contains a file
 * <b>BOX<i>nnnn</i>.TXT</b>, where <b><i>nnnn</i></b> can be any decimal
 * number, this will be used as the new log file.  In this way the filename
 * allows you to assign a specific box number to a dedicated unit.  If no
 * such file exists on the media, file "BOX0999.TXT" is created.
 * Another file on the SD-Card is <a href="../../CONFIG.TXT"><i>CONFIG.TXT</i></a>
 * which contains the configuration for the MomoAudio.  Have a look at the example
 * configuration file for a description of all possible variables defined in
 * @ref l_CfgVarList.
 * - Removing an SD-Card
 * -# Generate a log message by some action, e.g. with a transponder,
 *      to force a LogFlush().
 *   -# Wait about 5 seconds (@ref LOG_SAMPLE_TIMEOUT) until the green LED
 *      starts flashing.  Log data is now written to the SD-Card.
 *   -# When the green LED stops flashing, you have a guaranteed duration
 *      of 15 seconds (@ref LOG_FLUSH_PAUSE) where no further data will be
 *      written to the SD-Card.
 *   -# Remove the SD-Card within this time.  The message "SD-Card removed"
 *      will be displayed on the LCD for 20 seconds.  All newly generated log
 *      messages will be stored in memory until another media is available.
 *
 * - Inserting an SD-Card
 *   -# Just insert the SD-Card into the slot.  The message "SD-Card inserted"
 *      will be displayed on the LCD.
 *   -# The file system on the SD-Card will be mounted and the free space of
 *      the media is reported.
 *   -# If a firmware update file (*.UPD) exists on the SD-Card, a reboot will
 *      be initiated to pass control to the booter.
 *   -# Otherwise the firmware looks for a "BOX<n>.TXT" file to use as new log
 *      file.
 *
 * @subsection ssa08 Battery Monitor
 * The battery pack has its own controller.  It is connected to the EFM32
 * microcontroller via I2C-bus.  The battery monitor requests status
 * information from the battery pack and logs this on a regular basis, i.e.
 * every @ref BAT_MON_INTERVAL seconds.
 *
 * @subsection ssa09 Low-Energy UART
 * The Low-Power UART (LEUART) provides a connection to a host computer (PC).
 * It can be used as monitoring and debugging interface.  All log messages,
 * written to the SD-Card, are sent through this interface also.  This behaviour
 * can be changed by defining @ref LOG_MONITOR_FUNCTION to @ref NONE.
 * The format of this UART is 9600 baud, 8 data bits, no parity.
 *
 * @subsection Power_Outputs Power Outputs
 * There are 8 switchable power outputs:
 * - <b>UA1</b> from DC/DC converter IC3
 * - <b>UA2</b> from DC/DC converter IC4
 * - <b>SERVO</b> from BATT_INPUT via FET T12
 * - <b>LINEAR</b> from BATT_INPUT via FET T13
 * - <b>RFID1</b> from VMCU via FET T4
 * - <b>RFID2</b> from VMCU via FET T7
 * - <b>RFID3</b> from VMCU via FET T9
 * - <b>RFID_GND_LB</b> switchable ground via FET T5
 * For the MOMO application only UA1 and UA2 are used.
 *
 * All of these outputs can be switched on or off at selectable times.  Up to
 * five <b>on</b> and <b>off</b> times can be defined via configuration
 * variables in file <a href="../../CONFIG.TXT"><i>CONFIG.TXT</i></a>, see
 * @ref alarm_times.
 *
 * If the @ref RFID_Reader is configured for one of this outputs, it will
 * automatically be enabled or disabled together with the respective power
 * output.  The same appears to @ref SCALES.
 * @subsection ssa10 Firmware
 * The firmware consists of an initialization part and a main loop, also called
 * service execution loop.  The initialization part sets up all modules, enables
 * devices and interrupts.  The service execution loop handles all tasks that
 * must not be executed in interrupt context.
 *
 * After power-up or reset the following actions are performed:
 * -# Basic initialization of MCU and clocks
 * -# Low-Energy UART is set up
 * -# LEDs are switched on for test purposes (lamp test)
 * -# The logging facility is initialized and the firmware version is logged
 * -# Further hardware initialization (DCF77, RFID reader, Light
 *    Barriers, SD-Card interface, Interrupts, Alarm Clock, and Control Module)
 * -# LEDs are switched off after 4 seconds
 * -# The DCF77 Atomic Clock is enabled to receive the time signal
 * -# When valid times have been received twice, the system clock is set and
 *    alarm times are converted to the appropriate time zone (MEZ or MESZ)
 * -# Alarm times are checked against the current time, devices are enabled
 *    when time is in range
 *
 * The program then enters the Service Execution Loop which takes care of:
 * - Power management for the RFID reader
 * - SD-Card change detection, re-mounting the filesystem, and reading the
 *   configuration file <a href="../../CONFIG.TXT"><i>CONFIG.TXT</i></a>
 * - Battery monitoring
 * - Writing the log buffer to the SD-Card
 * - Entering the right energy mode
 *
 * @section cfg Configuration Variables
 * The behaviour of the system can be changed by setting configuration
 * variables in the file <a href="../../CONFIG.TXT"><i>CONFIG.TXT</i></a>
 * which resides on the SD-Card.  It follows a description of these variables.
 *
 * <b>A Note about Time Variables:</b><br>
 * The system clock always starts with <b>standard</b> time, i.e. <b>MEZ</b>.
 * When the @ref DCF77_Atomic_Clock time has been received, and this notifies
 * <b>daylight saving time</b>, i.e. <b>MESZ</b>, all alarm times will be
 * converted to MESZ by adding one hour.  This requires time variables, e.g.
 * @ref alarm_times to be set in <b>MEZ</b> time zone, even if MESZ is
 * currently valid.<br>
 *
 * @subsection alarm_times ON_TIME_1~5, OFF_TIME_1~5
 * These variables determine the ON and OFF time for the RFID reader
 * and Audio module.
 * @subsection ssb01 Operating time of the MOMO_AUDIO 
 * These variables determine the on and off time of the MOMO_AUDIO.  When it
 * is in the off state, the rifd reader and audio module are switched off.
 * Rfid Reader triggerd by Lightbarriers are ignored. 
 * see @ref alarm_times.
  *   
 * @subsection LB_FILTER_DURATION
 * Light barrier (LB) filter duration in seconds.  The LB may change its
 * state several times during a bird is picking food.  To prevent the
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
int main( void )
{
    /* Initialize chip - handle erratas */
    CHIP_Init();

    /* EFM32 NVIC implementation provides 8 interrupt levels (0~7) */
    NVIC_SetPriorityGrouping (4);	// 8 priority levels, NO sub-priority
        
    /* Set up clocks */
    cmuSetup();

    /* Init Low Energy UART with 9600bd (this is the maximum) */
    drvLEUART_Init (9600);

#ifdef DEBUG
    dbgInit();
#endif

    /* Output version string to SWO or LEUART */
    drvLEUART_puts("\n***** MOMO_AUDIO V");
    drvLEUART_puts(prj.Version);
    drvLEUART_puts(" *****\n\n");

    /* Configure PA2 to drive the red Power-On LED (LED1) - show we are alive */
    GPIO_PinModeSet (POWER_LED_PORT, POWER_LED_PIN, gpioModePushPull, 1);

    /* Configure PA5 to drive the green Ready LED - show we are alive */
    GPIO_PinModeSet (LOG_FLUSH_LED_PORT, LOG_FLUSH_LED_PIN, gpioModePushPull, 1);

    /*
     * All modules that make use of external interrupts (EXTI) should be
     * initialized before calling ExtIntInit() because this enables the
     * interrupts, so IRQ handler may be executed immediately!
     */

    /* Initialize Logging (do this early) */
    LogInit();

    /* Log Firmware Revision and Clock Info */
    Log ("MOMO AUDIO V%s (%s %s)", prj.Version, prj.Date, prj.Time);
    uint32_t freq = CMU_ClockFreqGet(cmuClock_HF);
    Log ("Using %s Clock at %ld.%03ldMHz",
	 CMU_Select_String[CMU_ClockSelectGet(cmuClock_HF)],
	 freq / 1000000L, (freq % 1000000L) / 1000L);
    
#ifdef DEBUG
    MemInfo();		// report available memory
#endif
    
     /* Initialize DCF77 hardware, configure Interrupt */
    DCF77Init();
  
    /* Initialize Light Barrier hardware, configure Interrupt */
    LB_Init();

    /* Initialize SD-Card Interface */
    DiskInit();

    /* Introduce Power-Fail Handlers, configure Interrupt */
    PowerFailInit (l_PowerFailFct);

    /* Initialize External Interrupts */
    ExtIntInit (l_ExtIntCfg);

    /* Initialize the Alarm Clock module */
    AlarmClockInit();

    /* Initialize control module */
    ControlInit();

    /* Switch Log Flush LED OFF */
    LOG_FLUSH_LED = 0;

    /* Initialize Battery Monitor */
    BatteryMonInit();

    /* Enable the DCF77 Atomic Clock Decoder */
    DCF77Enable();

    /* Enable all other External Interrupts */
    ExtIntEnableAll();


    /* ============================================ *
     * ========== Service Execution Loop ========== *
     * ============================================ */
    while (1)
    {
	/* Check for power-fail */
	if (! PowerFailCheck())
	{
#if ENABLE_LEUART_RECEIVER
	    /* Check for command from Debug Console */
	    CheckCommand();
#endif
            /* Check if to power-on or off the RFID reader */
	    RFID_Check();
                                    
            /* Check if to power-on or off Audio module */
           // AudioCheck();
            
       	    /* Check if SD-Card has been inserted or removed */
	    if (DiskCheck())
	    {
		/* First check if an "*.UPD" file exists on this SD-Card */
		if (FindFile ("/", "*.UPD") != NULL)
		{
		    /*
		     * In this case the SD-Card contains update images.  We must
		     * pass control to the booter to perform a firmware upgrade.
		     */
		    Reboot();
		}

		/* New File System mounted - (re-)open Log File */
		LogFileOpen("BOX*.TXT", "BOX0999.TXT");

		/* Be sure to flush current log buffer so it is empty */
		LogFlush(true);	// keep SD-Card power on!

		/* Log information about the MCU and the battery */
		uint32_t uniquHi = DEVINFO->UNIQUEH;
		Log ("MCU: %s HW-ID: 0x%08lX%08lX",
		     PART_NUMBER, uniquHi, DEVINFO->UNIQUEL);
		LogBatteryInfo (BAT_LOG_INFO_VERBOSE);
                
                /* Clear (previous) Configuration - switch devices off */
		ClearConfiguration();
                 
                /* Read and parse configuration file */
		CfgRead(CONFIG_FILE_NAME);

                /* Initialize RFID reader according to (new) configuration */
		RFID_Init();
               
                /* Initialize Audio module according to (new) configuration */
		AudioInit();
                
                /* Flush log buffer again and switch SD-Card power off */
	       LogFlush(false);
                                   
               /* See if devices must be switched on at this time */
               CheckAlarmTimes();
            }
            
	    /* Check Battery State */
	    BatteryCheck();
            
             /* Check if to power-on or off Audio module */
            AudioCheck();
                      
            /* Check if to flush the log buffer */
	    LogFlushCheck();
        
        }

	/*
	 * Check for current power mode:  If a minimum of one active module
	 * requires EM1, i.e. <g_EM1_ModuleMask> is not 0, this will be
	 * entered.  If no one requires EM1 activity, EM2 is entered.
	 */
	if (! g_flgIRQ)		// enter EM only if no IRQ occurred
	{
	    if (g_EM1_ModuleMask)
		EMU_EnterEM1();		// EM1 - Sleep Mode
	    else
	   	EMU_EnterEM2(true);	// EM2 - Deep Sleep Mode
	}
	else
	{
	    g_flgIRQ = false;	// clear flag to enter EM the next time
	}
    }
}


/******************************************************************************
 * @brief   Configure Clocks
 *
 * This local routine is called once from main() to configure all required
 * clocks of the EFM32 device.
 *
 *****************************************************************************/
static void cmuSetup(void)
{
    /* Start LFXO and wait until it is stable */
    CMU_OscillatorEnable(cmuOsc_LFXO, true, true);

#if USE_EXT_32MHZ_CLOCK
    /* Start HFXO and wait until it is stable */
    CMU_OscillatorEnable(cmuOsc_HFXO, true, true);

    /* Select HFXO as clock source for HFCLK */
    CMU_ClockSelectSet(cmuClock_HF, cmuSelect_HFXO);

    /* Disable HFRCO */
    CMU_OscillatorEnable(cmuOsc_HFRCO, false, false);
#endif

    /* Route the LFXO clock to the RTC and set the prescaler */
    CMU_ClockSelectSet(cmuClock_LFA, cmuSelect_LFXO);	// RTC, LETIMER
    CMU_ClockSelectSet(cmuClock_LFB, cmuSelect_LFXO);	// LEUART0/1
    CMU_ClockEnable(cmuClock_RTC, true);

    /* Prescaler of 1 = 30 us of resolution and overflow each 8 min */
    CMU_ClockDivSet(cmuClock_RTC, cmuClkDiv_1);

    /* Enable clock to low energy modules */
    CMU_ClockEnable(cmuClock_CORELE, true);

    /* Enable clock for HF peripherals (ADC, DAC, I2C, TIMER, and USART) */
    CMU_ClockEnable(cmuClock_HFPER, true);

    /* Enable clock to GPIO */
    CMU_ClockEnable(cmuClock_GPIO, true);
}


/******************************************************************************
 * @brief   Reboot
 *
 * This local routine brings the system into a quiescent state and then
 * generates a reset.  It is typically used to transfer control from the
 * application to the booter for firmware upgrades.
 *
 *****************************************************************************/
static void Reboot(void)
{
int	n, i;

     /* Disable external interrupts */
    ExtIntDisableAll();

    /* Shut down peripheral devices */
    BatteryMonDeinit();
    RFID_PowerOff();
    AudioPowerOff();
    DCF77Disable();

    drvLEUART_puts ("Shutting down system for reboot\n");

    /*
     * Show LED Pattern before resetting:
     * 3x 5-short-pulses, separated by a pause,
     * finally a dimming LED from maximum brightness to off.
     */
    for (n = 0;  n < 3;  n++)		// 3x patterns
    {
	for (i = 0;  i < 5;  i++)	// a' 5 pulses
	{
	    POWER_LED = 1;
	    msDelay(100);
	    POWER_LED = 0;
	    msDelay(100);
	}
	msDelay(800);			// pause
    }

    for (n = 0;  n < 200;  n++)
    {
	POWER_LED = 1;
	for (i = 0;  i < (200 - n);  i++)
	    DelayTick();

	POWER_LED = 0;
	for (i = 0;  i < n;  i++)
	    DelayTick();
    }

    /* Perform RESET */
    NVIC_SystemReset();
}


/***************************************************************************//**
 * @brief   Set Error Condition
 *
 * @param[in] errorSource
 *	Enum of type @ref ERR_SRC to identify the error source.
 *
 * This routine sets an error condition for the specified source.  The error
 * conditions of the system are stored as single bits in the local variable
 * @ref l_ErrorFlags.  If one or more errors are active, the red LED is on.
 *
 * @see
 * ClearError()
 *
 *****************************************************************************/
void	SetError (ERR_SRC errorSource)
{
    Bit(l_ErrorFlags, errorSource) = 1;
    POWER_LED = 1;
}
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

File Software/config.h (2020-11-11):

/***************************************************************************//**
 * @file
 * @brief	Project configuration file
 * @author	Ralf Gerhauser / Peter Loes
 * @version	2016-02-27
 *
 * This file allows to set miscellaneous configuration parameters.  It must be
 * included by all modules.
 *
 ****************************************************************************//*
Revision History:
2016-02-26,rage	Increased LOG_BUF_SIZE to 4KB.
2016-02-10,rage	Set DFLT_RFID_POWER_OFF_TIMEOUT to 6 minutes.
2014-11-11,rage	Derived from project "AlarmClock".
*/

#ifndef __INC_config_h
#define __INC_config_h

/*=============================== Header Files ===============================*/

#include <stdio.h>
#include <stdbool.h>
#include "em_device.h"

/*=============================== Definitions ================================*/

/*
 * Basic defines
 */
    /* terminators for lists and strings */

#define	EOL		NULL		/* EndOfList		*/
#define EOS		'\0'		/* EndOfString		*/
#define	NONE		(-1)

    /* macro to calculate the number of elements of an array */
#define ELEM_CNT(array)  (sizeof (array) / sizeof ((array)[0]))

/*
 * LED Definitions for this project
 */
    /*!@brief GPIO Port of the (red) Power-LED. */
#define POWER_LED_PORT		gpioPortA
    /*!@brief GPIO Pin of the (red) Power-LED is PA2. */
#define POWER_LED_PIN		2
    /*! @brief Macro to set or clear the Power-LED */
#define POWER_LED   IO_Bit(GPIO->P[POWER_LED_PORT].DOUT, POWER_LED_PIN)
    /*!@brief GPIO Port of the (green) Log Flush LED. */
#define LOG_FLUSH_LED_PORT	gpioPortA
   /*!@brief GPIO Pin of the (green) Log Flush LED is PA5. */
#define LOG_FLUSH_LED_PIN	5		//! State: 0=OFF, 1=ON
    /*! @brief Macro to set or clear the Log Flush LED */
#define LOG_FLUSH_LED IO_Bit(GPIO->P[LOG_FLUSH_LED_PORT].DOUT, LOG_FLUSH_LED_PIN)

/*!
 * @brief MPU Clock Configuration.
 *
 * Set to 0 to use the internal RC oscillator, if 1 the external 32MHz XTAL
 * is used.  The frequency of the RC oscillator is 14MHz per default.
 */
#define USE_EXT_32MHZ_CLOCK	1

/*
 * Configuration for module "AlarmClock"
 */
    /*!@brief RTC frequency in [Hz]. */
#define RTC_COUNTS_PER_SEC	32768


/*!
 * @brief Interrupt Priority Settings
 *
 * There are 8 priority levels 0 to 7 with 0 to be the highest and 7 to be
 * the lowest priority.  DCF77 (which is called from the EXTI handler) and RTC
 * must use the same priority level to lock-out each other, because they
 * both use function localtime() and this is not multithreading save.
 * Funktion localtime_r() would be the right choice here, unfortunately it
 * is not available with the IAR compiler library.
 */
#define INT_PRIO_UART	2		//!<  UART IRQs for RFID and Scales
#define INT_PRIO_LEUART	2		//!<  LEUART RX interrupt (not used)
#define INT_PRIO_DMA	2		//!<  DMA is used for LEUART
#define INT_PRIO_SMB	2		//!<  SMBus used by the battery monitor
#define INT_PRIO_RTC	3		//!<  lower priority than others
#define INT_PRIO_EXTI	INT_PRIO_RTC	//!<  must be the same as @ref INT_PRIO_RTC


/*
 * Configuration for Atomic Clock module "DCF77.c"
 */
    /*!@brief Use Hardware Enable pin of the DCF77 receiver. */
#define DCF77_HARDWARE_ENABLE	1

    /*!@brief Activate DCF77 only once per day. */
#define DCF77_ONCE_PER_DAY	1

    /*!@brief Call ShowDCF77Indicator() to flash red LED on DCF77 signal. */
#define DCF77_INDICATOR		1

/*
 * Configuration for module "RFID"
 */

   /*!@brief Duration in [s] during the RFID reader tries to read an ID. */
#define DFLT_RFID_DETECT_TIMEOUT	 20	// 20s

/*
 * Configuration for module "Logging"
 */
    /*!@brief Size of the log buffer in bytes. */
#define LOG_BUF_SIZE	4096

    /*!@brief Use this define to specify a function to be called for monitoring
     * the log activity.  Here, monitoring is done via the LEUART interface.
     */
#define LOG_MONITOR_FUNCTION	drvLEUART_puts

/* forward declaration */
void    drvLEUART_puts(const char *str);

    /*!@brief Disable "alive" message by setting this interval to 0. */
#define LOG_ALIVE_INTERVAL	0


/*!@name DMA Channel Assignment
 *
 * The following definitions assign the 8 DMA channels to the respective
 * devices or drivers.  These defines are used as index within the global
 * DMA_DESCRIPTOR_TypeDef structure @ref g_DMA_ControlBlock.
 */
//@{
#define DMA_CHAN_LEUART_RX	0	//! LEUART Rx uses DMA channel 0
#define DMA_CHAN_LEUART_TX	1	//! LEUART Tx uses DMA channel 1
//@}

/*!@brief Name of the configuration file. */
#define CONFIG_FILE_NAME	"CONFIG.TXT"

/*================================== Macros ==================================*/
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

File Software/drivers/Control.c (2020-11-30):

/***************************************************************************//**
 * @file
 * @brief	Sequence Control
 * @author      Ralf Gerhauser / Peter Loes  
 * @version	2018-08-03
 *
 * This is the automatic sequence control module.  It controls the power
 * outputs that may be activated via alarm times @ref alarm_times.
 * It controls peripheral units like Audio module playback & record.
 * This module also defines the configuration variables for the file
 * <a href="../../CONFIG.TXT"><i>CONFIG.TXT</i></a>.
 *
 ****************************************************************************//*
Revision History:
2020-01-03,rage	- Start and Stop Playback & Record
2017-05-02,rage	- ControlInit: Added CONTROL_INIT structure to specify the
		  power output.
		- PWR_OUT_DEF contains the bit address and logical enable level
		  for all power output pins.
		- ExtIntEnableAll() is called when switching the MOMOAudio on again
		  to consider the current state of all EXTI interrupt inputs.
		- Implemented PowerOutputs().
		- Removed CAM1 and CAM2 routines.
2017-01-25,rage	Initial version.
*/

/*=============================== Header Files ===============================*/


#include "em_cmu.h"
#include "em_int.h"
#include "em_gpio.h"
#include "Logging.h"
#include "LightBarrier.h"
#include "AlarmClock.h"
#include "RFID.h"
#include "Audio.h"
#include "CfgData.h"
#include "Control.h"


/*=============================== Definitions ================================*/

    /*!@brief Structure to define power outputs. */
typedef struct
{
    __IO uint32_t *BitBandAddr;	// Bit band address of GPIO power enable pin
    bool	   HighActive;	// true: The power enable pin is high-active
} PWR_OUT_DEF;

    /*!@brief Macro to calculate a GPIO bit address for a port and pin. */
#define GPIO_BIT_ADDR(port, pin)					\
	IO_BIT_ADDR((&(GPIO->P[(port)].DOUT)), (pin))

/*!@brief Macro to extract the port number from a GPIO bit address.  */
#define GPIO_BIT_ADDR_TO_PORT(bitAddr)		(GPIO_Port_TypeDef)	\
	(((((uint32_t)(bitAddr) - BITBAND_PER_BASE) >> 5)		\
	 + PER_MEM_BASE - GPIO_BASE) / sizeof(GPIO_P_TypeDef))

    /*!@brief Macro to extract the pin number from a GPIO bit address.  */
#define GPIO_BIT_ADDR_TO_PIN(bitAddr)					\
	(((uint32_t)(bitAddr) >> 2) & 0x1F)
          
/*================================ Global Data ===============================*/

    /*!@brief CFG_VAR_TYPE_ENUM_2: Enum names for Power Outputs. */
const char *g_enum_PowerOutput[] = { "UA2", "UA", NULL };
          
/*================================ Local Data ================================*/

    /*!@brief Power output port and pin assignment - keep in sync with enums
     * @ref PWR_OUT and string array @ref g_enum_PowerOutput !
     */
static const PWR_OUT_DEF  l_PwrOutDef[NUM_PWR_OUT] =
{   //   BitBandAddr,              HighActive
    { GPIO_BIT_ADDR(gpioPortA,  4), true },	// PWR_OUT_UA2
    { GPIO_BIT_ADDR(gpioPortA,  6), true },	// PWR_OUT_UA
};

    /*!@brief Default value of the playback_type, set by PLAYBACK_TYPE. */
static int32_t		l_dfltPlayType = DFLT_PLAY_TYPE;

    /*!@brief Actual duration of the playback_type, set by ID. */
static int32_t		l_PlayType = DFLT_PLAY_TYPE;

    /*!@brief Default keep playback duration, set by PLAYBACK. */
static int32_t		l_dfltKeepPlayback = DFLT_KEEP_PLAYING_DURATION;

    /*!@brief Actual keep playback duration, set by ID. */
static int32_t		l_KeepPlayback = DFLT_KEEP_PLAYING_DURATION;

    /*!@brief Default keep Record duration, set by RECORD. */
static int32_t		l_dfltKeepRecord = DFLT_KEEP_RECORD_DURATION;

    /*!@brief Actual keep Record duration, set by ID. */
static int32_t		l_KeepRecord = DFLT_KEEP_RECORD_DURATION;

    /*!@brief List of configuration variables.
     * Alarm times, i.e. @ref CFG_VAR_TYPE_TIME must be defined first, because
     * the array index is used to specify the alarm number \<alarmNum\>,
     * starting with @ref alarm_times, when calling AlarmSet().
     */
static const CFG_VAR_DEF l_CfgVarList[] =
{
 { "ON_TIME_1",		       CFG_VAR_TYPE_TIME,	NULL		},
 { "OFF_TIME_1",	       CFG_VAR_TYPE_TIME,	NULL		},
 { "LB_FILTER_DURATION",       CFG_VAR_TYPE_INTEGER,    &g_LB_FilterDuration  },
 { "RFID_TYPE",		       CFG_VAR_TYPE_ENUM_1,	&g_RFID_Type	},
 { "RFID_POWER",	       CFG_VAR_TYPE_ENUM_2,	&g_RFID_Power	},
 { "RFID_DETECT_TIMEOUT",      CFG_VAR_TYPE_INTEGER,	&g_RFID_DetectTimeout },
 { "AUDIO_POWER",              CFG_VAR_TYPE_ENUM_2,     &g_AudioPower	},
 { "AUDIO_CFG_VC",             CFG_VAR_TYPE_INTEGER,	&g_AudioCfg_VC	},
 { "AUDIO_CFG_ST",             CFG_VAR_TYPE_INTEGER,	&g_AudioCfg_ST	},
 { "AUDIO_CFG_IM",             CFG_VAR_TYPE_INTEGER,	&g_AudioCfg_IM	},
 { "AUDIO_CFG_RQ",             CFG_VAR_TYPE_INTEGER,	&g_AudioCfg_RQ	},
 { "PLAYBACK",                 CFG_VAR_TYPE_DURATION,	&l_dfltKeepPlayback },
 { "RECORD",	               CFG_VAR_TYPE_DURATION,	&l_dfltKeepRecord   },
 { "PLAYBACK_TYPE",            CFG_VAR_TYPE_INTEGER,	&l_dfltPlayType     },
 { "ID",                       CFG_VAR_TYPE_ID,	        NULL	            },
 {  NULL,                      END_CFG_VAR_TYPE,        NULL		    }
};
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

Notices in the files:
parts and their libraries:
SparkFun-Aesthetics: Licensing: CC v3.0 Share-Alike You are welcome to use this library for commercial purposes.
